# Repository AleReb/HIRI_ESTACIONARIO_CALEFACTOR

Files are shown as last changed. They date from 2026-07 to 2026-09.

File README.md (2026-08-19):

# HIRI AUCA con calefactor para Plantower

Proyecto de firmware y hardware para una estación ambiental HIRI AUCA basada en
ESP32, un sensor Plantower y un calefactor controlado por ESP8266. El calefactor
mide temperatura y humedad, protege el elemento térmico mediante termocupla y
entrega sus datos a la estación por un enlace serial dedicado.

## Estado vigente

| Componente | Archivo principal | Plataforma | Versión |
|---|---|---|---|
| Calefactor | `Calefactor_V2_0_0/Calefactor_V2_0_0.ino` | ESP8266 / NodeMCU | Firmware `1.0.0` |
| Estación HIRI | `HIRI_STATIC_CALEFACTOR_0_1/HIRI_STATIC_CALEFACTOR_0_1.ino` | ESP32 Dev Module | `CAL V0.0.1` |
| PCB calefactor | `PCB/calefactor.sch` y `PCB/calefactor.brd` | Autodesk EAGLE 9.6.2 | Diseño fuente |
| PCB HIRI ESP32/SIM7600 | `PCB/pcbesp32sim7600/Board_760032v2.sch` y `PCB/pcbesp32sim7600/Board_760032v2.brd` | Autodesk EAGLE 9.6.2 | Diseño fuente |
| PCB resistivo | `PCB/RESIS-CALOR.brd` | Autodesk EAGLE 9.6.2 | Diseño fuente |

El firmware histórico con DHT22 se conserva sólo como referencia. El calefactor
vigente usa SHT40; no requiere DHT22.

## Funciones principales

### Calefactor

- SHT40 para temperatura y humedad.
- BME280 como medición interna/respaldo.
- MAX6675 y termocupla para protección térmica.
- Relé en `D0`.
- Control por humedad con histéresis: enciende desde `65 % RH` y libera bajo
  `60 % RH`.
- Control por temperatura ambiental baja.
- Corte a `70 °C` y emergencia a `80 °C`.
- Prueba remota temporizada de 1 a 300 segundos, siempre subordinada a la
  protección térmica.
- Reinicio programado cada 4 horas.

### HIRI AUCA

- Plantower PMS por software serial.
- Enlace independiente a 9600 baudios con el calefactor.
- OLED SSD1306, RTC DS3231, tarjeta SD, batería y NeoPixel.
- SIM7600 para red celular, HTTP y GNSS configurable.
- Guardado SD cada 3 minutos y envío HTTP cada 5 minutos.
- Consulta opcional de versión del calefactor, sin bloquear calefactores
  antiguos.

## Protocolo serial HIRI-calefactor

Las tramas son ASCII a `9600 8N1` y terminan en `*HH`, donde `HH` es la suma
de comprobación hexadecimal de 8 bits del texto anterior al asterisco.

El identificador vigente del calefactor es `CALEF`; HIRI también acepta `CAL`
para equipos anteriores.

```text
HIRI,1,HELLO*HH
CALEF,1,HELLO,1.0.0*HH

HIRI,1,VERSION*HH
CALEF,1,VERSION,1.0.0*HH

HIRI,1,TEMP,valor*HH
HIRI,1,CAL,segundos*HH

CALEF,1,DATA,tempExt,tempSHT,tempBME,humSHT,humBME,tempTermocupla,
             rele,porHumedad,porTemperatura,emergencia*HH
```

La consulta `VERSION` es opcional. HIRI la envía al arrancar y luego cada 30
segundos durante un máximo de 3 minutos. La ausencia de respuesta no detiene el
arranque, la adquisición, el guardado ni el uso del calefactor.

## Estructura

- `Calefactor_V2_0_0/`: firmware vigente del calefactor.
- `HIRI_STATIC_CALEFACTOR_0_1/`: firmware vigente de la estación.
- `PCB/`: esquemáticos y placas EAGLE del calefactor, del elemento resistivo y
  de la estación HIRI con ESP32/SIM7600; consultar su README antes de fabricar.
- `documentacion/`: documentación del calefactor, cambios y antecedentes.
- `codigo_original/`: respaldos históricos; no son el firmware recomendado.

## Compilación

```powershell
arduino-cli compile --fqbn esp8266:esp8266:nodemcuv2 Calefactor_V2_0_0
arduino-cli compile --fqbn esp32:esp32:esp32 HIRI_STATIC_CALEFACTOR_0_1
```

Se requieren las librerías Arduino indicadas por los `#include` de cada
sketch. Antes de cargar, sustituir el puerto de ejemplo por el puerto real.

## Documentación

- [Documentación del calefactor](documentacion/README.md)
- [Documentación de HIRI](HIRI_STATIC_CALEFACTOR_0_1/README.md)
- [PCB y advertencias de fabricación](PCB/README.md)
- [Licencia y atribución](LICENSE.md)
- [Descargo de responsabilidad](DISCLAIMER.md)

## Autor y licencia

Creación original: **Alejandro Rebolledo**

Contacto: **arebolledo@udd.cl**

Salvo los componentes de terceros identificados por separado, el firmware, la
documentación y los diseños PCB originales de este repositorio se ofrecen bajo
[Creative Commons Attribution-NonCommercial 4.0 International](LICENSE.md).
Se permite compartir y adaptar con atribución, únicamente para fines no
comerciales. El uso comercial requiere autorización separada del autor.

Este proyecto se entrega tal cual y no constituye un producto certificado.
Revise el [descargo de responsabilidad](DISCLAIMER.md) antes de construir,
energizar o desplegar el equipo.

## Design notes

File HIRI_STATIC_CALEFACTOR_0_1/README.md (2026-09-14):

# HIRI AUCA 4 con calefactor

Firmware para una estación ambiental estática basada en ESP32. Integra un
Plantower, un calefactor externo, OLED, RTC, SD, batería, SIM7600 y GNSS
configurable.

## Estado vigente

- Sketch: `HIRI_STATIC_CALEFACTOR_0_1.ino`
- Plataforma: `esp32:esp32:esp32`
- Versión mostrada por el firmware: `CAL V1.0.1`
- Dispositivo activo: `HIRI-AUCA-4`
- `DEVICE_ID_STR`: `4`
- SSID local: `HIRI-AUCA-4`
- APN: `flolive.net`
- API: `http://api-sensores.cmasccp.cl/insertarMedicion`

## Hardware y pines

| Función | Pines ESP32 |
|---|---|
| SIM7600 | TX 27, RX 26, PWRKEY 4, DTR 32, FLIGHT 25 |
| Plantower PMS | RX 18, TX 5 por `SoftwareSerial` |
| Calefactor | RX2 19, TX2 23 a 9600 baudios |
| SD HSPI | SCLK 14, MISO 2, MOSI 15, CS 13 |
| Batería | ADC 35 |
| Alimentación auxiliar | GPIO 33 |
| NeoPixel | GPIO 12 |
| BTN1 | GPIO 39, activo en LOW y con resistencia externa |
| BTN2 | Deshabilitado (`-1`) |
| Enable/alimentación I2C | GPIO 0 (`I2C_POWER_PIN`) |
| OLED/RTC | Bus I2C: SDA 21 y SCL 22, valores predeterminados del ESP32 usados por `Wire.begin()` |

### Comportamiento actual de GPIO0 e I2C

El firmware vigente configura GPIO0 como salida y lo coloca directamente en
`HIGH` al comienzo de `setup()`. Después espera aproximadamente 600 ms antes de
ejecutar `Wire.begin()`. El bus se configura con timeout de 50 ms y reloj de
50 kHz.

La secuencia implementada actualmente es:

```text
GPIO0 OUTPUT
GPIO0 HIGH
espera 300 ms
inicialización Serial/watchdog
espera 300 ms
Wire.begin()
```

Esta variante **no ejecuta** el power-cycle `LOW -> HIGH` presente en el
firmware estático anterior. Tampoco contiene la función de recuperación
`recoverI2CBus()` ni el comando serial `i2c reset`.

Los comentarios de `config.h` describen GPIO0 como control activo en HIGH:
`LOW` corta la alimentación y `HIGH` energiza el bus. Esa es la intención del
firmware; durante diagnóstico de hardware se debe confirmar la polaridad real
midiendo tanto GPIO0 como la alimentación conmutada de OLED/RTC.

## Funciones activas

- Plantower: PM1.0, PM2.5, PM10 y T/RH cuando el modelo los entrega.
- Calefactor: SHT40, BME280, termocupla, relé y banderas de control.
- RTC DS3231.
- SD con CSV diario y archivos de error/transmisiones fallidas.
- HTTP por SIM7600.
- GNSS opcional; apagado por defecto.
- OLED con vistas rotativas de Plantower, calefactor y sistema; agrega GPS
  cuando GNSS está habilitado.
- Reinicio programado cada 3 horas.

## Detección y versión del calefactor

HIRI acepta el identificador vigente `CALEF` y el histórico `CAL`. Al arrancar
envía una consulta `VERSION` no bloqueante. Si no hay respuesta, reintenta cada
30 segundos durante un máximo de 3 minutos y luego deja de consultar.

La falta de versión no impide usar un calefactor antiguo. HIRI acepta tanto
`CAL,1,HELLO` sin versión como `CAL/CALEF,1,HELLO,<versión>`; `HELLO` o `DATA`
siguen estableciendo la conexión. Cuando se recibe una versión válida, se
muestra como `CALEFACTOR FW <versión>` en la OLED.

## Revisión de arranque

La ventana de inicio contiene:

```text
OLED
SD
RTC
PLANTOWER
CALEFACTOR
```

En `CALEFACTOR`, el estado inicial confirma que la UART quedó configurada. Si
la versión llega durante la ventana de revisión, se muestra en esa fila. La
ausencia de `VERSION` no se informa como fallo.

## Configuración operativa

En cada arranque el firmware fuerza:

```text
SD auto-mount:      ON
Guardado SD:        180000 ms (3 min)
Envío HTTP:         300000 ms (5 min)
Autostart:          ON
Esperar GPS:        OFF
```

Defaults al restablecer configuración:

```text
Timeout HTTP:       15 s
OLED auto-off:      OFF
NeoPixel:           ON, brillo 50 %
GNSS:               OFF
Modo GNSS:          15
Reinicio:           3 h
```

## Payload HTTP

Se envían exactamente 16 valores:

| Posición | Valor |
|---:|---|
| 1 | Latitud |
| 2 | Longitud |
| 3 | CSQ |
| 4 | Velocidad GNSS |
| 5 | Satélites |
| 6 | Voltaje |
| 7 | Temperatura Plantower |
| 8 | Humedad Plantower |
| 9 | PM1.0 |
| 10 | PM2.5 |
| 11 | PM10 |
| 12 | Temperatura SHT40 del calefactor |
| 13 | Humedad SHT40 del calefactor |
| 14 | Estado del relé |
| 15 | Temperatura BME280 del calefactor |
| 16 | Humedad BME280 del calefactor |

Los datos no disponibles se representan con `-1`.

Para `DEVICE_ID_STR = "4"`:

```text
idsSensores=1165,1165,1165,1165,1165,1166,1167,1167,1167,1167,1167,1203,1203,1203,1203,1203
idsVariables=11,12,15,45,46,4,3,6,7,8,9,3,6,57,58,59
```

## Tarjeta SD

Archivo diario:

```text
/HIRI_AUCA_4_DD_MM_AAAA.csv
```

Columnas:

```text
timestamp,pm_1_0_ug_m3,pm_2_5_ug_m3,pm_10_ug_m3,
temp_plantower_c,hum_plantower_pct,
temp_interna_calefactor_bme_c,hum_interna_calefactor_bme_pct,
temp_externa_calefactor_sht40_c,hum_externa_calefactor_sht40_pct,
relay_calefactor,senal_csq,conexion_http,
latitud,longitud,velocidad_kmh,satelites,voltaje_v
```

Archivos auxiliares:

- `/errors_h4.csv`
- `/failed_h4.csv`

## Interfaz actual

La pantalla normal rota automáticamente entre vistas de estación. BTN1 ejecuta
una prueba manual compuesta por envío HTTP, guardado SD y solicitud de
calefacción por 10 segundos. BTN2 avanzaría la pantalla, pero está deshabilitado
en la configuración de pines actual.

Las estructuras de menú todavía existen en `ui.ino`, pero el flujo de render y
botones vigente retorna desde la vista de estación antes de navegar esos menús.
Consulte `documentacion/menu_structure.md`.

## Compilación

Desde la carpeta superior:

```powershell
arduino-cli compile --fqbn esp32:esp32:esp32 HIRI_STATIC_CALEFACTOR_0_1
```

## Documentación, licencia y seguridad

- [Manual técnico](documentacion/MANUAL_TECNICO.md)
- [Manual de usuario](documentacion/MANUAL_USUARIO.md)
- [Interfaz actual](documentacion/menu_structure.md)
- [Licencia del proyecto](../LICENSE.md)
- [Descargo de responsabilidad](../DISCLAIMER.md)

Creación original: **Alejandro Rebolledo** (`arebolledo@udd.cl`).

Licencia: **CC BY-NC 4.0**.

## Proteccion de conexion y modo SD

`StrikesConect` es el contador global de intentos consecutivos de conexion;
`MAX_STRIKES_CONECT = 3` fija el limite. Se incrementa antes de entrar en las
llamadas bloqueantes y se limpia al establecer la conexion de datos. Se conserva
en memoria RTC ante reinicios por software/watchdog, sin escribir la flash.

Los fallos 1 y 2 provocan un reinicio controlado. El fallo 3 activa
`connectionOffline`: se suspenden los intentos celulares y GNSS, se mantiene
el muestreo y se intenta guardar en SD en la primera vuelta del loop y luego
cada 3 minutos. Si un reinicio interrumpe el tercer intento, el siguiente
arranque entra directamente en modo SD. Apagar y volver a encender inicia
una nueva serie de intentos. No hay recuperacion automatica de red en modo SD.

La cabecera muestra `SD OK` si esta montada y no se ha detectado un error de
escritura, o `SD ERR` si falta la tarjeta o falla abrir/escribir el CSV.
Sin SD ni conexion se siguen leyendo sensores, pero no se pueden conservar
las mediciones. No se implementa montaje automatico de una tarjeta insertada
posteriormente; se puede montar desde la funcion WiFi SD existente.

TinyGSM alimenta ahora el watchdog desde `TINY_GSM_YIELD`, dentro de sus esperas
AT. Un reset antes de este cambio podia ocurrir al esperar 60 segundos por la
red con un watchdog de 60 segundos. Tambien se elimino el pulso repetido de
PWRKEY durante la espera de arranque. Los tiempos de espera siguen siendo
bloqueantes; el cambio evita el reset del watchdog, no los convierte en tareas
asincronicas.

Pruebas de banco pendientes:

- Sin cobertura y con SD: verificar strikes 1, 2 y 3, solo dos reinicios y
  crecimiento del CSV cada 3 minutos con `SIN_RED_MODO_SD`.
- Sin cobertura ni SD: verificar modo de medicion estable y `SD ERR`.
- Con red desde encendido: verificar contador en cero y envio HTTP normal.
- Retirar la SD durante muestreo: verificar `SD ERR` tras el siguiente guardado.
- Cortar y restablecer alimentacion: verificar nuevos intentos de conexion.
- Revisar el motivo de reinicio serial para distinguir watchdog de brownout.

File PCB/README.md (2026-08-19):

# Diseños PCB

Esta carpeta contiene fuentes de Autodesk EAGLE 9.6.2:

| Archivo | Contenido observado | Dimensión aproximada |
|---|---|---:|
| `calefactor.sch` | Esquemático del controlador del calefactor, 1 hoja y 11 componentes | No aplica |
| `calefactor.brd` | Placa del controlador con Wemos D1 Mini Pro, termocupla, dos conectores I2C, relé y serial | 48,30 × 78,09 mm |
| `RESIS-CALOR.brd` | Placa alargada del elemento resistivo/calefactor | 120,40 × 24,00 mm |
| `pcbesp32sim7600/Board_760032v2.sch` | Esquemático de la estación HIRI para ESP32 y SIM7600 | No aplica |
| `pcbesp32sim7600/Board_760032v2.brd` | Placa de la estación HIRI correspondiente al firmware `HIRI_STATIC_CALEFACTOR_0_1` | Fuente EAGLE |

## Correspondencia con el firmware

El firmware vigente usa:

- Wemos/ESP8266;
- MAX6675 y termocupla;
- BME280 y SHT40 por I2C;
- relé;
- enlace serial con HIRI.

El esquemático y la placa conservan un conector rotulado `DHT`. Es una herencia
del diseño anterior y no significa que el firmware vigente utilice DHT22. El
SHT40 vigente se conecta por I2C. Antes de fabricar se debe comprobar en EAGLE
la asignación real de cada conector, señal y pin contra
`Calefactor_V2_0_0/Calefactor_V2_0_0.ino`.

El diseño `pcbesp32sim7600/Board_760032v2` corresponde al firmware de la
estación ubicado en
`HIRI_STATIC_CALEFACTOR_0_1/HIRI_STATIC_CALEFACTOR_0_1.ino`. Incluye la placa y
el esquemático para la electrónica basada en ESP32 y SIM7600, además de las
conexiones de los periféricos de HIRI. Antes de fabricar, también se deben
comparar las señales y los pines del diseño contra ese sketch.

## Estado de fabricación

No se incluyen Gerbers, archivos de perforado, BOM aprobada ni resultados de
DRC/ERC. Estos archivos deben considerarse fuentes editables, no un paquete de
fabricación liberado.

Antes de fabricar:

1. Ejecutar ERC en `calefactor.sch`.
2. Confirmar que `calefactor.brd` corresponde al esquemático vigente.
3. Ejecutar DRC con las reglas del fabricante.
4. Revisar anchos de pista, corriente, separación y aislamiento del circuito
   térmico y del relé.
5. Verificar huellas, polaridades, conectores y dimensiones mecánicas.
6. Revisar `RESIS-CALOR.brd` mediante cálculo térmico y eléctrico independiente.
7. Generar y revisar Gerbers y perforaciones antes de enviar a producción.
8. Ejecutar ERC y DRC sobre `pcbesp32sim7600/Board_760032v2.sch` y
   `pcbesp32sim7600/Board_760032v2.brd`, y verificar su correspondencia con el
   firmware HIRI vigente.

Consulte [el descargo de responsabilidad](../DISCLAIMER.md). Los diseños
originales se distribuyen bajo [CC BY-NC 4.0](../LICENSE.md).

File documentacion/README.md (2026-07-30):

# Documentación vigente del calefactor

Fuente de verdad:
`../Calefactor_V2_0_0/Calefactor_V2_0_0.ino`.

## Identificación

- Generación del proyecto: Calefactor V2.
- Versión de firmware: `1.0.0`.
- Plataforma: ESP8266 / NodeMCU.
- ID de protocolo vigente: `CALEF`.
- ID histórico aceptado por HIRI: `CAL`.

## Hardware utilizado por el firmware

| Función | Componente o pin |
|---|---|
| Temperatura/humedad externa | SHT40 por I2C |
| Temperatura/humedad interna | BME280 en dirección `0x76` |
| Protección térmica | MAX6675: SO `D6`, SCK `D5`, CS `D8` |
| Salida del relé | `D0` |
| Serial hacia HIRI | RX `D3`, TX `D4`, 9600 8N1 |

El DHT22 sólo pertenece al firmware histórico.

## Control implementado

- Muestreo cada 1 segundo.
- Humedad: activa desde `65 % RH`, desactiva bajo `60 % RH`.
- Temperatura mínima de referencia: `15 °C`.
- Corte de relé por termocupla inválida, igual a cero o desde `70 °C`.
- Emergencia desde `80 °C`; recuperación bajo `70 °C`.
- Prueba manual serial de 1 a 300 segundos con las mismas protecciones.
- Reinicio automático cada 4 horas.

## Protocolo

Las tramas usan checksum aditivo hexadecimal `*HH`.

```text
HIRI,1,HELLO*HH
HIRI,1,VERSION*HH
HIRI,1,TEMP,valor*HH
HIRI,1,CAL,segundos*HH

CALEF,1,HELLO,1.0.0*HH
CALEF,1,VERSION,1.0.0*HH
CALEF,1,DATA,...*HH
```

La consulta de versión no es obligatoria para operar. HIRI puede usar
calefactores antiguos que sólo entreguen `HELLO` o `DATA`.

## Documentos

- [Cambios V2](cambios_v2_0_0.md)
- [Revisión histórica del código DHT22](revision_codigo.md)
- [Humedad y medición PM2.5](humedad_pm25_literatura.md)
- [Recomendaciones de diseño](recomendaciones.md)
- [PCB](../PCB/README.md)

Los documentos históricos se conservan como antecedentes y están marcados como
tales. Para comportamiento ejecutable prevalece siempre el sketch vigente.

## Seguridad y licencia

Creación original: Alejandro Rebolledo, arebolledo@udd.cl.

Licencia: [CC BY-NC 4.0](../LICENSE.md).

Lea el [descargo de responsabilidad](../DISCLAIMER.md) antes de energizar el
calefactor o fabricar los PCB.

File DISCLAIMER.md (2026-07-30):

# Descargo de responsabilidad

Este repositorio contiene firmware experimental, diseños electrónicos y
documentación técnica. No constituye un producto terminado, certificado ni
aprobado para seguridad funcional, metrología reglamentaria, uso médico,
protección de personas o control de procesos críticos.

El calefactor puede involucrar temperaturas elevadas, corriente eléctrica,
elementos resistivos y relés. Un error de diseño, montaje, firmware, conexión,
selección de componentes o disipación puede producir sobretemperatura,
incendio, choque eléctrico, daño a sensores, pérdida de datos o lesiones.

Antes de construir o utilizar el sistema, el usuario o integrador debe:

- revisar independientemente esquemáticos, PCB, pistas, aislaciones,
  conectores, polaridades, protecciones y capacidad de corriente;
- instalar fusibles, límites térmicos independientes y medios de desconexión
  adecuados al riesgo;
- verificar la termocupla, el relé y el estado seguro ante fallas;
- validar el equipo en un entorno controlado antes del despliegue;
- realizar calibración y validación metrológica de los sensores;
- cumplir las normas eléctricas, ambientales, de radiofrecuencia, seguridad y
  protección de datos aplicables en el lugar de uso.

Los archivos PCB se entregan como fuentes de diseño y no como archivos de
fabricación aprobados. Deben pasar revisión eléctrica, mecánica, DRC/ERC y de
seguridad antes de generar Gerbers o fabricar.

El software, la documentación y el hardware se proporcionan **tal cual**, sin
garantías expresas ni implícitas de exactitud, seguridad, comerciabilidad,
ausencia de defectos o aptitud para un propósito particular. En la máxima
medida permitida por la ley, Alejandro Rebolledo y los colaboradores no asumen
responsabilidad por daños directos, indirectos, incidentales o consecuentes,
pérdida de datos, lucro cesante, lesiones o daños materiales derivados del uso
o imposibilidad de uso del proyecto.

El usuario es responsable de evaluar si el proyecto es apropiado para su caso
de uso y asume los riesgos de construcción, modificación, operación y
despliegue.

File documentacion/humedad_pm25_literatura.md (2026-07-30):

# Humedad relativa y sensores PM2.5 tipo Plantower

## Contexto

Los sensores Plantower/PMS5003 estiman PM por dispersion de luz. No pesan directamente el material particulado: convierten senales opticas en conteos y concentraciones mediante algoritmos internos. Por eso sus lecturas dependen de propiedades opticas, tamano de particula, composicion y humedad.

## Que dice la literatura

### 1. Plantower admite operacion hasta alta humedad, pero advierte condiciones con niebla/agua

El manual del PMS5003 indica rango de humedad de trabajo de `0~99%`. Tambien advierte que, en condiciones como niebla de agua, bano/termas u outdoor, se debe agregar proteccion. Esto significa que el sensor puede operar en aire humedo, pero no implica que la medicion sea exacta en alta humedad o con condensacion/aerosol de agua.

Fuente: Plantower PMS5003 series data manual.

### 2. La humedad relativa puede producir sobreestimacion

Una revision/laboratorio sobre sensores de bajo costo indica que, en humedad relativa alta, el efecto higroscopico puede sobreestimar la salida del sensor. Tambien cita que para Plantower PMS5003 el efecto empieza a observarse sobre aproximadamente 65-70% RH.

Fuente: *Calibration of Low-cost Sensors for Measurement of Indoor Particulate Matter Concentrations via Laboratory/Field Evaluation*, AAQR.

### 3. El mecanismo fisico es el crecimiento higroscopico

Cuando la humedad relativa sube, algunas particulas absorben agua. Eso cambia su tamano y su indice de refraccion efectivo. Como el sensor optico mide luz dispersada, puede interpretar ese cambio como mas particulas o mas masa PM2.5, aunque parte del aumento sea agua.

Fuente: Patel et al. 2024, *Towards a hygroscopic growth calibration for low-cost PM2.5 sensors*, Atmospheric Measurement Techniques.

### 4. La composicion del aerosol importa

El efecto de humedad no es igual para todos los aerosoles. Particulas con sulfatos, nitratos u otras fracciones mas higroscopicas absorben mas agua. Por eso una regla fija universal de humedad puede mejorar, pero no garantiza exactitud absoluta.

Fuente: Patel et al. 2024; Frontiers 2021 field evaluation of Plantower PMS5003.

### 5. Se han propuesto correcciones por humedad

Patel et al. 2024 desarrollan una calibracion para PMS5003 que incorpora crecimiento higroscopico y parametros estacionales. En San Francisco, la calibracion con dependencia estacional de RH redujo el RMSE cerca de 40% frente a datos sin calibrar.

## Implicancia para este calefactor

Si el calefactor esta antes del Plantower, su justificacion tecnica probable es reducir la humedad relativa del aire que entra al sensor, o evitar condensacion. Calentar el aire sin agregar vapor de agua baja la humedad relativa, aunque no cambia la humedad absoluta.

Ejemplo conceptual:

- Aire frio y humedo entra al sistema.
- El calefactor aumenta la temperatura del flujo.
- Al subir la temperatura, la capacidad del aire para contener vapor aumenta.
- La humedad relativa baja.
- Baja el riesgo de condensacion y se reduce parte del sesgo optico asociado al crecimiento higroscopico.

El firmware vigente mide humedad con SHT40 y usa una histéresis de `65 % RH` para activar y `60 % RH` para desactivar el control por humedad. Aún es recomendable registrar una medición adicional después del calefactor para validar experimentalmente la reducción de RH antes del Plantower.

## Umbrales utiles para documentar o probar

Estos valores no son reglas universales, pero sirven como punto de partida experimental:

- RH < 60%: zona generalmente menos problematica.
- RH 65-70%: literatura reporta inicio de efecto higroscopico en PMS5003 en algunos casos.
- RH 74-80%: estudios de laboratorio reportan debilitamiento de desempeno dependiendo de composicion.
- RH > 85%: evaluaciones de campo muestran influencia clara y respuesta no lineal.
- RH cercana a 95% o condensacion: zona de alto riesgo para datos y hardware.

## Fuentes consultadas

- Plantower PMS5003 series data manual: https://www.aqmd.gov/docs/default-source/aq-spec/resources-page/plantower-pms5003-manual_v2-3.pdf
- Patel, M. Y. et al. 2024. *Towards a hygroscopic growth calibration for low-cost PM2.5 sensors*. Atmospheric Measurement Techniques. https://amt.copernicus.org/articles/17/1051/2024/
- *Calibration of Low-cost Sensors for Measurement of Indoor Particulate Matter Concentrations via Laboratory/Field Evaluation*. AAQR. https://aaqr.org/articles/aaqr-23-04-jk-0097.pdf
- *Field Calibration and Evaluation of an Internet-of-Things-Based Particulate Matter Sensor*. Frontiers in Environmental Science. https://www.frontiersin.org/journals/environmental-science/articles/10.3389/fenvs.2021.798485/full

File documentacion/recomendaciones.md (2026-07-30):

# Recomendaciones y contexto histórico

> Nota de vigencia: el DHT22 fue retirado. El firmware activo usa SHT40 en `Calefactor_V2_0_0/Calefactor_V2_0_0.ino`. Las referencias siguientes a `dhthum` y `dhttemp` son ejemplos del firmware original y se conservan como antecedente.

## Diagnostico

El firmware original controlaba temperatura mínima y protección por sobretemperatura, pero no cerraba el lazo con humedad. El firmware vigente ya incorpora ese control mediante SHT40.

## Recomendacion principal

Usar una condición de control basada en humedad relativa, idealmente medida cerca de la entrada del Plantower y después del calefactor. En `Calefactor V2`, firmware `1.0.0`, se implementó con SHT40 e histéresis `65% RH ON / 60% RH OFF`.

Ejemplo histórico de regla simple con DHT22 (no usar en el firmware vigente):

```cpp
const float humedadObjetivo = 60.0;
const float humedadAlta = 70.0;

bool humedadAltaDetectada = (dhthum > humedadAlta || humBMP > humedadAlta);
bool temperaturaBaja = (tempBMP < minimo || tempsens < minimo || dhttemp < minimo);
bool calefactorSeguro = (tempThermo > 0 && tempThermo < maxcontrol);

if ((temperaturaBaja || humedadAltaDetectada) && calefactorSeguro) {
  digitalWrite(relay, HIGH);
} else {
  digitalWrite(relay, LOW);
}
```

Esta regla no debe copiarse sin probar: hay que decidir que sensor de humedad representa mejor el flujo que entra al Plantower.

## Mejor opcion de control

Usar dos criterios:

1. Seguridad termica del calefactor:
   - Apagar si `tempThermo >= maxcontrol`.
   - Emergencia si `tempThermo >= maxemergencia`.
   - Apagar ante falla de termocupla.

2. Calidad de medicion PM2.5:
   - Encender calefactor si RH antes del Plantower supera 65-70%.
   - Apagar o modular cuando RH baje a 55-60%.
   - Usar histeresis para evitar prendido/apagado rapido.

Ejemplo de histéresis implementada en el firmware 1.0.0:

```cpp
const float rhOn = 65.0;
const float rhOff = 60.0;
bool heaterByHumidity = false;

if (rhEntradaPlantower >= rhOn) {
  heaterByHumidity = true;
}
if (rhEntradaPlantower <= rhOff) {
  heaterByHumidity = false;
}
```

## Medicion recomendada

Para validar el sistema, registrar como minimo:

- PM1.0, PM2.5, PM10 del Plantower.
- Temperatura y humedad antes del calefactor.
- Temperatura y humedad despues del calefactor o cerca de la entrada del Plantower.
- Temperatura de la termocupla del calefactor.
- Estado del rele.
- Fecha/hora.

Con esos datos se puede comprobar si el calefactor realmente baja la humedad relativa que ve el Plantower.

## Punto de rocio

Una mejora es calcular punto de rocio. Si la temperatura del flujo o de superficies internas se acerca al punto de rocio, aumenta el riesgo de condensacion.

El control puede buscar:

- Mantener la temperatura del aire que entra al Plantower varios grados sobre el punto de rocio.
- Evitar exceder la temperatura maxima recomendada del sensor.

## Cambios de codigo recomendados

- DHT22 reemplazado por SHT40 en `Calefactor V2`, firmware `1.0.0`.
- Validar `isnan()` en lecturas ambientales. Implementado en el firmware `1.0.0`.
- Separar estado de sensores fallidos de valores fisicos como `999`.
- Incluir estado del rele en la salida de datos. Implementado en el firmware `1.0.0`.
- Incluir banderas de error: BME ausente, SHT40 inválido y termocupla inválida.
- Evitar `while (emergencyMode)` bloqueante; usar un estado de emergencia no bloqueante. Implementado en el firmware `1.0.0`.
- Cambiar `restartInterval` a `const unsigned long`. Implementado en el firmware `1.0.0`.
- Corregir comentarios con caracteres mal codificados.

## Decision tecnica

Para un documento academico o informe, la frase correcta seria:

> El prototipo mide humedad relativa, pero la version actual del firmware no la utiliza para controlar el calefactor. El control se basa en umbrales de temperatura y proteccion por termocupla. Dado que la literatura identifica la humedad relativa como un factor relevante en sensores opticos PM2.5 tipo Plantower, se recomienda incorporar una regla de control por RH o punto de rocio y validar experimentalmente la reduccion de RH en la entrada del sensor.

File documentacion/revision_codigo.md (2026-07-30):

# Revisión técnica histórica: firmware original con DHT22

> Este documento describe exclusivamente el firmware original respaldado en `codigo_original/Calefactor_bmp_dht22_serialcheck_v3_original.ino`. El firmware vigente usa SHT40 y está en `Calefactor_V2_0_0/Calefactor_V2_0_0.ino`; no utiliza DHT22.

Archivo analizado: `Calefactor_bmp_dht22_serialcheck_v3.ino`

## Hardware asumido

- MCU: ESP8266, por el uso de pines `D0`...`D8` y `ESP.wdtFeed()`.
- Sensor ambiental BME280 por I2C, direccion `0x76`.
- Sensor DHT22 en `D7`.
- Termocupla con MAX6675 por SPI en `D5`, `D6`, `D8`.
- Rele del calefactor en `D0`.
- Comunicacion serial secundaria por `SoftwareSerial`:
  - `externo_RX = D3`
  - `externo_TX = D4`

## Variables principales

- `tempsens`: temperatura recibida desde el puerto serial secundario. Parte en `16`.
- `tempBMP`: temperatura del BME280.
- `humBMP`: humedad relativa del BME280.
- `dhttemp`: temperatura del DHT22.
- `dhthum`: humedad relativa del DHT22.
- `tempThermo`: temperatura del calefactor medida por MAX6675.
- `minimo = 15`: umbral inferior de temperatura.
- `maxcontrol = 70`: temperatura maxima normal del calefactor.
- `maxemergencia = 80`: umbral de emergencia.

## Flujo de operacion

1. Inicializa watchdog, serial principal, serial externo, SPI, rele, MAX6675, BME280 y DHT22.
2. Si falla BME280, marca `statusBME = false` y despues reporta `999` en temperatura/humedad BME.
3. Cada vez que llega una linea por `externo`, valida checksum y actualiza `tempsens`.
4. Cada 280 ms lee:
   - MAX6675.
   - BME280, si esta disponible.
   - DHT22.
5. Imprime una linea CSV:

```text
tempsens,dhttemp,tempBMP,dhthum,humBMP,tempThermo
```

6. Enciende el rele si alguna de estas temperaturas esta bajo `15 C`:
   - `tempBMP`
   - `tempsens`
   - `dhttemp`
7. Apaga el rele si `tempThermo >= 70 C` o si `tempThermo == 0`.
8. Entra a modo emergencia si `tempThermo >= 80 C`; sale cuando baja de `80 C`.
9. Reinicia el ESP cada 4 horas con `Ticker`.

## Punto critico: humedad medida pero no usada

El codigo mide humedad:

```cpp
humBMP = bme.readHumidity();
dht.humidity().getEvent(&event);
dhthum = event.relative_humidity;
```

Pero la humedad solo se imprime/transmite. No aparece en la condicion de control del rele:

```cpp
if (tempBMP < minimo or tempsens < minimo or dhttemp < minimo)
```

Por lo tanto, si la humedad relativa sube a 70%, 80% o 90%, el calefactor no necesariamente encendera. Solo encendera si alguna temperatura baja de 15 C.

## Riesgos y observaciones

### 1. El calefactor no controla directamente la causa del sesgo PM2.5

La literatura indica que el problema de los sensores opticos PM2.5 no es solo baja temperatura, sino humedad relativa alta, condensacion y crecimiento higroscopico. El codigo actual no usa `dhthum` ni `humBMP` para activar el calefactor.

### 2. Lecturas invalidas del DHT22 no se filtran

Si el DHT22 entrega `NaN`, la comparacion `dhttemp < minimo` no se comporta como una lectura valida. Conviene validar con `isnan()`.

### 3. Uso de `tempBMP = 999` si falla BME280

Esto evita que el BME280 active el calefactor, pero tambien oculta la falla dentro de la logica de control. Para seguridad, una falla de sensor deberia quedar separada como estado de error.

### 4. `tempThermo == 0` apaga el rele

Puede ser una proteccion contra error de termocupla. Es correcto como idea, pero deberia documentarse y reportarse como falla. Una termocupla desconectada podria no entregar exactamente cero en todos los casos.

### 5. Modo emergencia con `while`

Durante emergencia el codigo queda bloqueado en un `while`. Sigue leyendo la termocupla y enviando datos, pero no procesa nuevas entradas seriales ni actualiza DHT/BME. Para seguridad esta bien apagar el rele, pero para telemetria conviene evitar bloqueo total.

### 6. Intervalo de lectura DHT22 demasiado corto

El loop intenta leer DHT22 cada 280 ms. El DHT22 normalmente requiere intervalos mas largos entre lecturas, tipicamente alrededor de 2 s. Leerlo tan rapido puede aumentar lecturas invalidas o repetidas.

### 7. `restartInterval` como `int`

`4 * 60 * 60 * 1000` cabe en un entero de 32 bits, pero no en 16 bits. En ESP8266 suele funcionar porque `int` es 32 bits, pero es mejor declararlo como `const unsigned long`.

### 8. `String` en ESP8266

El uso repetido de `String` en loops largos puede fragmentar memoria en algunos escenarios. Si el sistema debe operar meses, conviene evaluar buffers `char[]` o reducir concatenaciones.

## Interpretacion funcional

El programa actual puede describirse como:

> Controlador de calefactor por umbral de temperatura minima, con proteccion por termocupla y telemetria ambiental de temperatura/humedad.

No deberia describirse como:

> Controlador de humedad para estabilizar lecturas PM2.5.

Para que esa segunda frase sea correcta, la humedad debe entrar en la regla de control o al menos en un algoritmo de compensacion/documentacion experimental.

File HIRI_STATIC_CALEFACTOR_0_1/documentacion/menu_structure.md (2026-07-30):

# Interfaz OLED vigente

Este documento describe el flujo que realmente ejecuta `ui.ino`.

## Vista normal

`renderDisplay()` llama directamente a `drawStationView()`. La vista rota cada
10 segundos.

Con GNSS apagado:

1. Plantower.
2. Calefactor.
3. Estado de la estación.

Con GNSS encendido:

1. GPS y hora.
2. Plantower.
3. Calefactor.
4. Estado de la estación.

## Botones activos

### BTN1

En la vista normal realiza una prueba manual:

- envío HTTP;
- guardado SD del payload;
- solicitud de calefacción por 10 segundos.

También atiende cancelación o salida en algunos estados transitorios.

### BTN2

En la vista normal avanza a la siguiente pantalla. La configuración vigente usa
`BUTTON_PIN_2=-1`, por lo que no hay un segundo botón físico activo.

## Estados transitorios

El enum `DisplayState` conserva:

```text
DISP_NORMAL
DISP_SD_SAVED
DISP_MESSAGE
DISP_PROMPT
DISP_NETWORK
DISP_RTC
DISP_STORAGE
DISP_GPS
DISP_WIFI
```

Las rutinas de render para esos estados permanecen disponibles, aunque varias
se alcanzan sólo desde código o funciones heredadas.

## Menús retenidos pero no activos

`ui.ino` todavía declara arreglos para:

- menú principal;
- Mensajes;
- Configuración;
- Información.

Sin embargo, el render normal no dibuja esos menús y los manejadores BTN1/BTN2
retornan desde la lógica de vista de estación antes de ejecutar la navegación
heredada. Por tanto, esos arreglos no representan una interfaz accesible en el
firmware actual.

Si se reactiva el menú, se deben revisar los retornos anticipados de
`ui_btn1_click()`, `ui_btn2_click()` y `renderDisplay()`, asignar un GPIO real a
BTN2 y actualizar este documento y el manual de usuario.

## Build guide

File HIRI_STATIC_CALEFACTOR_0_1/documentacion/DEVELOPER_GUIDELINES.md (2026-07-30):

# Guía de mantenimiento

## Fuente de verdad

- Sketch principal: `HIRI_STATIC_CALEFACTOR_0_1.ino`
- Versión actual: variable `VERSION`, hoy `CAL V0.0.1`
- ID de estación: `DEVICE_ID_STR`, hoy `4`
- Protocolo de calefactor: `heater_serial.ino`

El directorio `build/` contiene artefactos y copias generadas; no debe usarse
como fuente para editar ni documentar.

## Regla de cambios

Todo cambio funcional debe:

1. actualizar `VERSION` según la política de releases;
2. registrarse en `documentacion/CAMBIOS.md`;
3. actualizar README y manuales afectados;
4. compilar con Arduino CLI;
5. validarse en hardware antes de declararse liberado.

## Elementos que deben mantenerse sincronizados

| Cambio | Documentos |
|---|---|
| Pines o hardware | README, manual técnico y PCB README |
| OLED o botones | manual de usuario y `menu_structure.md` |
| Protocolo del calefactor | ambos README y manual técnico |
| CSV o HTTP | README y manual técnico |
| Comandos | manuales técnico y de usuario |
| Defaults | README y manual técnico |
| Licencia/autoría | README, `LICENSE.md` y `DISCLAIMER.md` |

## Compilación

Desde la carpeta superior:

```powershell
arduino-cli compile --fqbn esp32:esp32:esp32 HIRI_STATIC_CALEFACTOR_0_1
```

Calefactor:

```powershell
arduino-cli compile --fqbn esp8266:esp8266:nodemcuv2 Calefactor_V2_0_0
```

## Checklist mínimo

- Compilan ambos sketches.
- HIRI acepta IDs `CALEF` y `CAL`.
- La falta de respuesta `VERSION` no bloquea la operación.
- Plantower y calefactor entregan datos o fallan de forma controlada.
- El CSV coincide con la cabecera documentada.
- HTTP contiene exactamente 16 valores.
- OLED y botones coinciden con `menu_structure.md`.
- SD, RTC, SIM7600, watchdog y reinicio programado funcionan.
- PCB se revisa mediante ERC/DRC antes de fabricación.

## Autoría y redistribución

Conservar la atribución a Alejandro Rebolledo (`arebolledo@udd.cl`), el aviso
CC BY-NC 4.0, la indicación de cambios y el descargo de responsabilidad.

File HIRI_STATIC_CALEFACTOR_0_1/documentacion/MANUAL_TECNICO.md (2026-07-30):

# Manual técnico — HIRI AUCA con calefactor

Referencia comprobada contra el código vigente el 30 de julio de 2026.

- Sketch principal: `HIRI_STATIC_CALEFACTOR_0_1.ino`
- Versión: `CAL V0.0.1`
- Equipo: `HIRI-AUCA-4`
- Plataforma: ESP32 Dev Module

## 1. Arquitectura

| Archivo | Responsabilidad vigente |
|---|---|
| `HIRI_STATIC_CALEFACTOR_0_1.ino` | Estados globales, `setup`, `loop`, arranque, telemetría y scheduler |
| `heater_serial.ino` | Protocolo serial con el calefactor |
| `PMSandSensorEXTRA.ino` | Lectura Plantower y LED de PM2.5 |
| `sd_card.ino` | CSV, errores y transmisiones fallidas |
| `http.ino` | Sesión HTTP mediante SIM7600 |
| `gps.ino` | GNSS, NMEA, diagnóstico y XTRA |
| `rtc.ino` | RTC y sincronización |
| `wifi.ino` | AP, DNS cautivo y gestor SD |
| `ui.ino` | OLED y botones |
| `config.h`, `config.ino` | Pines, preferencias y defaults |
| `serial_commands.ino` | Consola serial USB |
| `helpers.ino` | Valores seguros, reset y logging |
| `animacion.ino` | Animación inicial |

## 2. Pines

```text
SIM7600:    TX27 RX26 PWRKEY4 DTR32 FLIGHT25
Plantower:  RX18 TX5
Calefactor: RX19 TX23 (Serial2, 9600 8N1)
SD HSPI:    SCLK14 MISO2 MOSI15 CS13
Batería:    ADC35
Power:      GPIO33
NeoPixel:   GPIO12
BTN1:       GPIO39, activo LOW, requiere resistencia externa
BTN2:       -1, deshabilitado
```

OLED SSD1306 y RTC DS3231 comparten I2C. En esta variante no existe en el código
un `I2C_POWER_PIN` ni rutinas de inicialización para SHT/ENS/gas locales; esas
referencias pertenecían a variantes anteriores.

## 3. Secuencia de arranque

1. Inicia Serial USB y watchdog.
2. Configura I2C a 50 kHz.
3. Carga preferencias y fuerza la política operativa de estación.
4. Monta SD y crea el CSV diario.
5. Detecta OLED y ejecuta la animación.
6. Inicia Plantower y `Serial2`.
7. Envía una solicitud opcional de versión al calefactor.
8. Detecta RTC.
9. Muestra por 3 segundos la revisión OLED mientras continúa leyendo el enlace
   del calefactor.
10. Inicializa botones, SIM7600, red, XTRA y GNSS.
11. Activa autostart, logging SD y envío HTTP.

La ventana de arranque muestra `OLED`, `SD`, `RTC`, `PLANTOWER` y `CALEFACTOR`.
El estado del calefactor confirma la UART; no exige soporte de `VERSION`.

## 4. Protocolo del calefactor

Tramas ASCII con checksum aditivo de 8 bits:

```text
HIRI,1,HELLO*HH
HIRI,1,VERSION*HH
HIRI,1,TEMP,<valor>*HH
HIRI,1,CAL,<1-300>*HH

CALEF,1,HELLO,<version>*HH
CALEF,1,VERSION,<version>*HH
CALEF,1,DATA,<10 valores>*HH
```

HIRI acepta tanto `CALEF` como el ID histórico `CAL`. También acepta el
`HELLO` histórico sin campo de versión (`CAL,1,HELLO`).

`DATA` contiene, en orden: temperatura externa recibida, temperatura SHT40,
temperatura BME280, humedad SHT40, humedad BME280, termocupla, relé, activación
por humedad, activación por temperatura y emergencia.

La conexión se considera sin datos si pasan más de 5 segundos desde el último
`DATA`. HIRI envía temperatura al calefactor cada 2 segundos y `HELLO` cada 5
segundos.

`VERSION` es opcional y no bloqueante. Se consulta al inicio y cada 30 segundos
por hasta 3 minutos. Una respuesta recibida por `HELLO` o `VERSION` detiene los
reintentos.

## 5. Bucle principal

El `loop()`:

1. alimenta watchdog y procesa botones;
2. atiende WiFi/DNS/Web si ese modo está activo;
3. procesa GNSS;
4. actualiza sensores auxiliares y señal;
5. lee Plantower;
6. atiende el serial del calefactor;
7. procesa comandos AT;
8. muestrea batería;
9. actualiza OLED;
10. guarda SD según periodo;
11. transmite HTTP según periodo;
12. procesa comandos USB y reinicio programado.

## 6. Configuración persistente

Preferencias `config`:

```text
sdAuto, sdSavePer, httpPer, httpTO, oledOff, oledTO,
ledEn, ledBr, autoStart, autoGPS, autoGPSTO,
rotDisp, rebootH, gnssEn, gnssMode
```

En cada boot se fuerzan `sdAutoMount=true`, guardado a 180 s, HTTP a 300 s,
autostart activo y espera GPS desactivada. El reinicio programado por defecto es
cada 3 horas.

## 7. HTTP

Endpoint:

```text
http://api-sensores.cmasccp.cl/insertarMedicion
```

El payload contiene 16 valores:

```text
lat,lon,csq,velocidad,satelites,voltaje,
tempPMS,humPMS,pm1,pm25,pm10,
tempSHTcalefactor,humSHTcalefactor,rele,
tempBMEcalefactor,humBMEcalefactor
```

Los datos inválidos se convierten a `-1`. Para el ID 4 se usan los sensores
`1165`, `1166`, `1167` y `1203` según el mapeo de `getIdsSensores()`.

## 8. SD

Archivo diario:

```text
/HIRI_AUCA_4_DD_MM_AAAA.csv
```

Las 18 columnas registran fecha/hora, PM, T/RH Plantower, T/RH BME del
calefactor, T/RH SHT40 del calefactor, relé, CSQ, resultado HTTP, posición,
velocidad, satélites y voltaje.

Logs:

- `/errors_h4.csv`
- `/failed_h4.csv`

## 9. UI real

`renderDisplay()` muestra directamente `drawStationView()` y rota entre:

- Plantower;
- calefactor;
- sistema;
- GPS/hora, sólo cuando GNSS está habilitado.

BTN1 ejecuta envío HTTP manual, guardado del mismo payload y una prueba del
calefactor por 10 segundos. BTN2 avanzaría la vista, pero está deshabilitado por
`BUTTON_PIN_2=-1`.

Los arreglos de menú permanecen en el fuente, pero el flujo vigente de botones
y render retorna antes de utilizarlos. No se deben documentar como interfaz
operativa hasta reactivar esa navegación.

## 10. Comandos seriales relevantes

Baudrate USB: 115200.

```text
help, cal <1-300>
rtc, rtcsync, modemtime
counters, resetcnt, stats
sdinfo, sdlist, sdnew, sdclear
netinfo, csq, sysinfo, mem, reboot
start, stop, config, configsave, configreset
set sdauto ..., set sdsave ..., set httpsend ..., set httptimeout ...
set oledoff ..., set oledtime ..., set led ..., set ledbright ...
set autostart ..., set gnss ..., set autowaitgps ...
set autogpsto ..., set rotatedisplay ..., set reboot ..., set gnssmode ...
```

La lista exacta y validaciones están en `serial_commands.ino`; `help` imprime la
ayuda disponible en el firmware cargado.

## 11. Compilación y QA

```powershell
arduino-cli compile --fqbn esp32:esp32:esp32 HIRI_STATIC_CALEFACTOR_0_1
```

Validar en hardware: boot, OLED, RTC, SD, Plantower, calefactor nuevo y antiguo,
termocupla, relé, SIM7600, HTTP, CSV y reinicio programado.

## 12. Seguridad, autoría y licencia

Creación original: Alejandro Rebolledo (`arebolledo@udd.cl`).

Licencia: [CC BY-NC 4.0](../../LICENSE.md).

Descargo: [DISCLAIMER.md](../../DISCLAIMER.md).

La protección de software a 70/80 °C no reemplaza fusibles, límites térmicos
independientes, revisión eléctrica ni validación del integrador.

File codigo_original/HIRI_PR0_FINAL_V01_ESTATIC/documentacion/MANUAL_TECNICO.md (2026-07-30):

# FirmwarePro - Manual Técnico

Versión de referencia: **Pro V0.1.27R**  
Sketch principal: **`HIRI_PR0_FINAL_V01_ESTATIC.ino`**  
Objetivo: documentación técnica para operación, mantenimiento e integración de la estación HIRI PR0 estática.

---

## 1. Arquitectura general

Firmware modular en archivos `.ino`:

- `HIRI_PR0_FINAL_V01_ESTATIC.ino`: núcleo, `setup()`, `loop()`, estados globales, sensores base, módem y scheduler.
- `config.h` / `config.ino`: pines, estructura `SystemConfig`, persistencia y defaults.
- `gps.ino`: GNSS, parser NMEA, watchdog, diagnósticos y XTRA.
- `PMSandSensorEXTRA.ino`: PMS5003, SDS198 y LED PM2.5.
- `sd_card.ino`: CSV diario, errores, failed_tx, headers y rotación por día.
- `http.ino`: ciclo HTTP por comandos AT del SIM7600.
- `wifi.ino`: AP, WebServer, DNSServer y captive portal.
- `ui.ino`: menú OLED, pantallas de estado, botones y modo debug.
- `serial_commands.ino`: CLI serial completa.
- `rtc.ino`: RTC y sincronización de hora.
- `helpers.ino`: utilidades de valores seguros y logging.
- `animacion.ino`: animación de arranque.

---

## 2. Hardware y pines activos

Definidos en `config.h` para la variante HIRIDUST/VALPO:

```text
SIM7600: TX27, RX26, PWRKEY4, DTR32, FLIGHT25
PMS5003: RX18, TX5 (SoftwareSerial)
SDS198 / Serial2: RX23, TX19
Batería: ADC35
NeoPixel: GPIO12
SD HSPI: SCLK14, MISO2, MOSI15, CS13
BTN1: GPIO39
BTN2: deshabilitado por defecto (-1)
I2C enable/power: GPIO0
```

Notas:

- `BTN1` usa lectura activa en LOW y requiere resistencia externa según la placa usada.
- `BTN2` solo se habilita si `BUTTON_PIN_2` se cambia desde `-1` a un GPIO real.
- `I2C_POWER_PIN` usa GPIO0 para controlar alimentación/enable de OLED y sensores I2C. En `setup()` parte en LOW, luego sube a HIGH, espera estabilización y recién después inicializa `Wire`.
- `POWER_PIN` existe como referencia histórica, pero no está activo en el flujo actual.

### Secuencia de alimentación I2C y OLED

1. `pinMode(I2C_POWER_PIN, OUTPUT)`.
2. `I2C_POWER_PIN = LOW` durante una ventana breve.
3. `I2C_POWER_PIN = HIGH`.
4. Espera de estabilización.
5. `configureI2CBus()` con `Wire.setTimeOut(50)` y reloj I2C a 50 kHz.
6. Detección de OLED en `0x3C` o `0x3D`.
7. `u8g2.begin()` y animación de arranque.
8. Ventana única de revisión de inicio.

La recuperación `recoverI2CBus()` ejecuta el mismo power-cycle sobre GPIO0, reinicia `Wire`, redetecta OLED y vuelve a inicializar sensores.

---

## 3. Configuración persistente

Namespace `config`:

- `sdAuto`, `sdSavePer`
- `httpPer`, `httpTO`
- `oledOff`, `oledTO`
- `ledEn`, `ledBr`
- `autoStart`, `autoGPS`, `autoGPSTO`, `autoDbg`
- `rotDisp`
- `gnssEn`, `gnssMode`

Defaults vigentes:

```text
sdAutoMount = true
sdSavePeriod = 180000 ms
httpSendPeriod = 300000 ms
httpTimeout = 15 s
oledAutoOff = false
ledEnabled = true
ledBrightness = 50 %
autostart = true
autostartWaitGps = false
autoDebug = true
rotateDisplay = false en configSetDefaults()
gnssEnabled = false
gnssMode = 15
```

Namespace `system`:

- `sendCnt`
- `sdCnt`
- `csvFile`
- `streaming`

Namespace `rtc`:

- `syncCnt`

---

## 4. Máquina de estados operativa

Estados funcionales relevantes:

- `streaming`: habilita transmisión HTTP periódica.
- `loggingEnabled`: habilita guardado SD periódico.
- `wifiModeActive`: habilita modo AP/Web.
- `uiFullMode`: activa vista completa/modo debug.
- `displayState`: subestados de UI (`DISP_NORMAL`, `DISP_MESSAGE`, `DISP_PROMPT`, `DISP_NETWORK`, `DISP_RTC`, `DISP_STORAGE`, `DISP_GPS`, `DISP_WIFI`).

Bucle principal:

1. Alimenta watchdog.
2. Procesa botones.
3. Si `wifiModeActive`, atiende DNS/WebServer, refresca display y retorna.
4. Si no hay WiFi activo:
   - Ejecuta GNSS solo si `config.gnssEnabled`.
   - Actualiza sensores.
   - Lee PMS/SDS198.
   - Actualiza LED PM2.5.
   - Atiende AT async.
   - Muestrea batería.
   - Refresca OLED.
   - Ejecuta watchdog de red, backoff HTTP y health log.
   - Guarda SD según `sdSavePeriod`.
   - Envía HTTP según `httpSendPeriod`.
   - Atiende comandos seriales.

---

## 5. Sensores

Sensores actuales:

- PMS5003: PM1.0, PM2.5, PM10, temperatura y humedad si están disponibles.
- SDS198: PM100/TSP por `Serial2`.
- SHT4x: temperatura y humedad externa principal.
- SHT31: temperatura y humedad alternativa/compatibilidad.
- DFRobot MultiGas I2C: concentración de gas.
- ENS160: TVOC, eCO2, AQI y validación de estado.
- RTC DS3231: tiempo y temperatura interna.
- ADC batería: promedio suavizado.

Mecanismos de robustez:

- Revisión secuencial de arranque por sensor con estado en Serial y OLED.
- Recuperación de bus I2C ante fallas repetidas.
- Power-cycle de OLED/sensores I2C usando GPIO0.
- Reintento/reinicialización para SHT4x y ENS160.
- Valores seguros para HTTP cuando una lectura no está disponible.

Durante el arranque se muestra una sola ventana de revisión con filas:

```text
I2C, OLED, SD, RTC, SHT4, SHT31, ENS, GAS
```

Cada fila se actualiza de `WAIT` a `...` y finalmente a `OK` o `FAIL`. Al terminar, la ventana queda visible cerca de 3 segundos.

---

## 6. GNSS

El subsistema GNSS existe, pero en la configuración de estación está **desactivado por defecto** (`gnssEnabled = false`).

Funciones clave:

- `gnssBringUp()`
- `setGnssAllWithFallback()`
- `gnssWatchdog()`
- `parseNMEA()`, `parseGGA()`, `parseRMC()`, `parseVTG()`, `parseGSA()`, `parseGSV()`
- `gnssDiagTick()`
- `gnssDebugPollAsync()`
- `detectAndEnableXtra()`
- `downloadXtraOnce()`
- `downloadXtraIfDue()`

Modos GNSS soportados:

- `1`: GPS
- `3`: GPS + GLONASS
- `5`: GPS + BEIDOU
- `7`: GPS + GLONASS + BEIDOU
- `15`: todas las constelaciones soportadas

---

## 7. SD y trazabilidad

`sd_card.ino` implementa:

- `generateCSVFileName()`: archivo diario por ID.
- `writeCSVHeader()`: cabecera controlada.
- `saveCSVData()`: registro de muestra y nota one-shot.
- `saveFailedTransmission()`: registro forense de fallas HTTP.
- `writeErrorLogHeader()`: log estructurado de errores.

Formato del CSV principal:

```text
ts_ms,time,gpsDate,lat,lon,alt,spd_kmh,pm1,pm25,pm10,pmsTempC,pmsHum,rtcTempC,batV,csq,sats,hdop,xtra_ok,sht31TempC,sht31Hum,sht4xTempC,sht4xHum,resetReason,pm100,gasPpm,tvoc,eco2,aqi,notas
```

Archivos:

- `/hiripro<ID>_DD_MM_YYYY.csv`
- `/errors_h<ID>.csv`
- `/failed_h<ID>.csv`

---

## 8. HTTP y red celular

Endpoint:

```text
http://api-sensores.cmasccp.cl/insertarMedicion
```

APN:

```text
flolive.net
```

Flujo HTTP:

1. Validación PDP/red.
2. `HTTPINIT`.
3. `HTTPPARA CID`.
4. `HTTPPARA URL`.
5. `HTTPACTION=0`.
6. Parseo de `+HTTPACTION:`.
7. `HTTPREAD` opcional.
8. `HTTPTERM`.

Mecanismos de robustez:

- Timeout configurable.
- Watchdog feed durante esperas.
- Registro de errores.
- Registro de URL fallida en SD.
- Contador de fallas consecutivas.
- Backoff HTTP tras fallas repetidas.
- Recuperación de módem.

---

## 9. Mapeo HTTP de sensores

`DEVICE_ID_STR` activo:

```text
12
```

`idsSensores` para dispositivo 12:

```text
1128,1129,1129,1130,1130,1130,1130,1130,1131,1132,1132,1132,1132,1132,1133,1134,1134
```

`idsVariables` común:

```text
53,54,55,11,12,15,45,46,4,3,6,7,8,9,51,3,6
```

Orden de `valores`:

```text
SO2/gas, TVOC, eCO2, latitud, longitud, CSQ, velocidad, satélites,
batería, temperatura PMS, humedad PMS, PM1.0, PM2.5, PM10,
PM100 SDS198, temperatura SHT, humedad SHT
```

Los datos faltantes o inválidos se envían como `-1`.

---

## 10. WiFi AP y gestor SD

`wifi.ino` implementa:

- `WiFi.softAP`.
- IP típica `192.168.4.1`.
- `DNSServer` en puerto 53.
- WebServer en puerto 80.

Rutas principales:

- `/`
- `/download`
- `/delete`
- `/rename`
- `/upload`
- `/delete_all`
- `/ip`
- `/ssid`

Controles:

- Sanitización básica de nombres.
- Validación de SD disponible.
- Límite de listado.
- Modo WiFi exclusivo para priorizar transferencias.

---

## 11. UI y botones

`ui.ino` implementa:

- Navegación por menú OLED.
- Confirmación para iniciar/detener muestreo.
- Pantallas de red, RTC, GPS y almacenamiento.
- Modo debug/full de telemetría.
- Pantalla WiFi dedicada.
- Notas one-shot desde menú Mensajes.

Controles lógicos:

- BTN1: navegar/cancelar; en modo debug ejecuta acción rápida de muestreo/transmisión.
- BTN2: seleccionar/confirmar; en modo debug sale al menú; en pantalla WiFi alterna WiFi SD.

En hardware actual, BTN2 está deshabilitado por defecto hasta asignar un GPIO real.

---

## 12. Serial CLI

Implementación en `serial_commands.ino`, entrada con `\n`, case-insensitive.

Comandos:

- `help`, `?`
- `rtc`, `rtcsync`, `modemtime`
- `counters`, `resetcnt`, `stats`
- `sdinfo`, `sdlist`, `sdnew`, `sdclear`, `sdclear confirm`
- `netinfo`, `csq`
- `sysinfo`, `mem`, `reboot`
- `i2c reset`
- `start`, `stop`
- `config`, `config sd`, `config http`, `config display`, `config power`
- `set sdauto on|off`
- `set sdsave 3|60|600|1200`
- `set httpsend 3|60|600|1200`
- `set httptimeout 5-30`
- `set oledoff on|off`
- `set oledtime 60|120|180`
- `set led on|off`
- `set ledbright 10|25|50|100`
- `set autostart on|off`
- `set gnss on|off`
- `set autowaitgps on|off`
- `set autogpsto 60-900`
- `set autodebug on|off`
- `set rotatedisplay on|off`
- `set gnssmode 1|3|5|7|15`
- `configreset`
- `configsave`

---

## 13. Validación QA

### Build

```bash
arduino-cli compile --fqbn esp32:esp32:esp32 .
```

### Flash

```bash
arduino-cli upload -p COMx --fqbn esp32:esp32:esp32 .
```

### Smoke test

1. Boot sin loop de reset.
2. GPIO0 sube a HIGH antes de inicializar I2C.
3. OLED muestra animación con versión e ID.
4. Ventana de revisión muestra `I2C`, `OLED`, `SD`, `RTC`, `SHT4`, `SHT31`, `ENS` y `GAS` con `OK/FAIL`.
5. SD monta y crea CSV.
6. Sensores entregan valores o fallan con logs controlados.
5. Módem registra red y obtiene CSQ.
6. HTTP responde o deja trazabilidad en `failed_h<ID>.csv`.
7. WiFi AP aparece como `HIRIPRO_12`.
8. Web SD responde en `192.168.4.1`.

Si GNSS se habilita, agregar validación de fix, satélites, HDOP y NMEA.

---

## 14. Riesgos y mejoras sugeridas

- Password AP por defecto fija.
- Falta autenticación HTTP para gestión SD.
- GNSS apagado por defecto puede producir campos de ubicación inválidos si no se habilita explícitamente.
- BTN2 deshabilitado requiere validación de flujo de UI según hardware final.
- Conviene agregar endpoint `/health`.
- Conviene automatizar pruebas de comandos seriales.
- Validar calibración de sensores antes de despliegue formal.

---

## Apéndice A. Logs frecuentes

- `[BOOT]`, `[READY]`
- `[MODEM]`, `[NET]`
- `[GNSS]`, `[GNSSDIAG]`, `[GSA]`, `[GSV]`
- `[HTTP]`
- `[SD]`, `[FAILED_TX]`
- `[CONFIG]`, `[SYSTEM]`
- `[UI]`

---

## Apéndice B. Disclaimer

Este firmware y este documento técnico se entregan **"as-is"** (tal cual), sin garantía de funcionamiento ininterrumpido ni adecuación a un caso de uso específico.

La validación metrológica, seguridad eléctrica, cumplimiento regulatorio y operación final son responsabilidad del integrador/desplegador.

Los autores no asumen responsabilidad por daños, pérdidas de datos o consecuencias derivadas del uso del sistema.

---

## Apéndice C. Licencia de documentación

Este manual se distribuye bajo:

**Creative Commons Attribution-NonCommercial 4.0 International (CC BY-NC 4.0)**  
https://creativecommons.org/licenses/by-nc/4.0/

Permisos principales:

- Compartir y adaptar con atribución.
- Uso no comercial.

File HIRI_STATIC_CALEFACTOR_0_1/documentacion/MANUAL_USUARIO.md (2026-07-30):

# Manual de usuario — HIRI AUCA 4

Firmware: `CAL V0.0.1`

Equipo: `HIRI-AUCA-4`

## Encendido

1. Compruebe cableado, antenas, termocupla, relé, Plantower y tarjeta SD.
2. Energice la estación y el calefactor.
3. La OLED muestra la animación y luego revisa:
   `OLED`, `SD`, `RTC`, `PLANTOWER` y `CALEFACTOR`.
4. La fila del calefactor confirma que el puerto serial fue iniciado. Si el
   equipo soporta consulta de versión, aparecerá su número.
5. La falta de número de versión no es un error: los calefactores antiguos
   siguen operando mediante sus datos normales.
6. La estación inicia automáticamente guardado SD y telemetría.

## Pantallas

Sin GNSS, la OLED rota entre:

- Plantower: PM1.0, PM2.5, PM10 y T/RH;
- calefactor: versión cuando existe, SHT40, BME280, termocupla y relé;
- sistema: ID, versión HIRI, batería, señal, contadores y modo.

Con GNSS habilitado se agrega GPS y hora.

## Botones

- BTN1 (GPIO39): ejecuta una acción manual de prueba:
  1. intenta un envío HTTP;
  2. guarda el mismo payload en SD;
  3. solicita 10 segundos de calefacción.
- BTN2 está deshabilitado en el firmware actual (`BUTTON_PIN_2=-1`).

La prueba térmica sólo es una solicitud: el calefactor la rechaza o la corta si
la termocupla es inválida, llega a 70 °C o existe una emergencia.

## Operación automática

```text
Guardado SD: cada 3 minutos
Envío HTTP: cada 5 minutos
Reinicio programado: cada 3 horas
GNSS: apagado por defecto
```

La estación consulta opcionalmente el firmware del calefactor durante los
primeros 3 minutos. Esas consultas no interrumpen ninguna otra función.

## Archivos SD

Datos diarios:

```text
/HIRI_AUCA_4_DD_MM_AAAA.csv
```

Logs:

```text
/errors_h4.csv
/failed_h4.csv
```

El CSV contiene PM, temperaturas, humedades, estado del relé, señal, resultado
HTTP, GNSS y batería.

## Consola USB

Conectar a 115200 baudios y terminación de línea `\n`.

Comandos útiles:

```text
help
cal 10
sdinfo
sdlist
netinfo
csq
sysinfo
start
stop
config
```

Use `cal N` sólo durante una prueba supervisada; `N` debe estar entre 1 y 300
segundos.

## Solución de problemas

### El calefactor no muestra versión

Puede ser un firmware antiguo. Si llegan mediciones y la pantalla indica datos
del calefactor, puede usarse normalmente. HIRI deja de consultar la versión
después de 3 minutos.

### No llegan datos del calefactor

- Verifique cruce TX/RX: calefactor TX hacia ESP32 RX19 y calefactor RX desde
  ESP32 TX23.
- Confirme 9600 baudios y tierra común.
- Revise las tramas `[CALEFACTOR]` en el monitor serial.
- Compruebe alimentación del ESP8266.

### No guarda en SD

Ejecute `sdinfo`, revise la tarjeta y compruebe que exista el archivo diario.

### No transmite

Ejecute `csq` y `netinfo`; revise antena, SIM, cobertura y
`/failed_h4.csv`.

### Lectura térmica inválida

No fuerce el relé. Revise MAX6675, termocupla, polaridad y conexión antes de
continuar.

## Seguridad y licencia

No deje una prueba del calefactor sin supervisión. El software no sustituye
protecciones térmicas y eléctricas independientes.

Autor original: Alejandro Rebolledo (`arebolledo@udd.cl`).

Licencia: [CC BY-NC 4.0](../../LICENSE.md).

Lea el [descargo de responsabilidad](../../DISCLAIMER.md).

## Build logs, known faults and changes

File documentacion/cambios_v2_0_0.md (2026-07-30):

# Cambios implementados en Calefactor V2 — firmware 1.0.0

## Control de version del firmware

La generacion de hardware/proyecto sigue siendo `Calefactor V2`. Su primera
version completa de firmware se identifica semanticamente como `1.0.0` mediante
la constante `CAL_FIRMWARE_VERSION`.

HIRI puede consultarla por el enlace serial de 9600 baudios:

```text
HIRI,1,VERSION*HH
CALEF,1,VERSION,1.0.0*HH
```

`HH` es la suma de comprobacion hexadecimal ya usada por el protocolo. La trama
`HELLO` tambien incluye la version para conservar la deteccion existente.

Archivo nuevo:

```text
Calefactor_V2_0_0/Calefactor_V2_0_0.ino
```

Respaldo del codigo original:

```text
codigo_original/Calefactor_bmp_dht22_serialcheck_v3_original.ino
```

## Cambio de sensor

Se elimino el uso de DHT22:

```cpp
#include <DHT.h>
#include <DHT_U.h>
```

Se agrego SHT40 por I2C usando la libreria de Adafruit:

```cpp
#include <Adafruit_SHT4x.h>
Adafruit_SHT4x sht4 = Adafruit_SHT4x();
```

La lectura principal de humedad para el control es `shtHum`. Si el SHT40 falla, el codigo puede usar `humBME` como respaldo.

## Nueva regla de activacion por humedad

La literatura reporta que el efecto higroscopico en PMS5003 puede comenzar cerca de `65-70% RH`. Por eso la version V2 usa:

```cpp
const float RH_ON = 65.0;
const float RH_OFF = 60.0;
const float RH_ALTA = 70.0;
```

La logica queda:

- Si `RH >= 65%`, el calefactor queda habilitado por humedad.
- Si `RH <= 60%`, se deshabilita el control por humedad.
- Si `RH >= 70%`, se imprime un aviso porque ya esta en zona alta de posible sesgo higroscopico.

La histeresis evita que el rele prenda y apague continuamente cerca de un solo umbral.

## Proteccion termica

Se mantiene la termocupla MAX6675 como proteccion del calefactor:

- Apaga el rele si la termocupla es invalida o entrega `0`.
- Apaga el rele si `tempThermo >= 70 C`.
- Entra en emergencia si `tempThermo >= 80 C`.
- Sale de emergencia solo cuando `tempThermo < 70 C`.

## Control combinado

El rele se activa si hay condicion de humedad o condicion de temperatura baja:

```cpp
setRelay(heaterByHumidity || heaterByTemperature);
```

Pero esa activacion solo ocurre si la termocupla esta en rango seguro.

## Salida de datos del firmware 1.0.0

La nueva salida CSV es:

```text
tempsens,shtTemp,tempBME,shtHum,humBME,tempThermo,relayOn,heaterByHumidity,heaterByTemperature,emergencyMode
```

Donde:

- `tempsens`: temperatura recibida por serial externo.
- `shtTemp`: temperatura del SHT40.
- `tempBME`: temperatura del BME280.
- `shtHum`: humedad relativa del SHT40.
- `humBME`: humedad relativa del BME280.
- `tempThermo`: temperatura de la termocupla MAX6675.
- `relayOn`: `1` si el rele esta encendido, `0` si esta apagado.
- `heaterByHumidity`: `1` si la humedad esta pidiendo calefaccion.
- `heaterByTemperature`: `1` si alguna temperatura baja esta pidiendo calefaccion.
- `emergencyMode`: `1` si esta en modo emergencia.

## Librerias requeridas

Ademas de las librerias ya usadas por el proyecto, el firmware 1.0.0 requiere:

- `Adafruit SHT4x Library`
- `Adafruit BusIO`
- `Adafruit Unified Sensor`

## Recomendacion de prueba

Antes de conectar el Plantower a una campana o flujo real, probar con monitor serial:

1. Confirmar que `shtHum` y `shtTemp` entregan valores validos.
2. Subir RH sobre `65%` y verificar `heaterByHumidity = 1` y `relayOn = 1`.
3. Bajar RH bajo `60%` y verificar `heaterByHumidity = 0`.
4. Calentar termocupla sobre `70 C` y verificar que `relayOn = 0`.
5. Confirmar que el rele no enciende si la termocupla falla o marca `0`.

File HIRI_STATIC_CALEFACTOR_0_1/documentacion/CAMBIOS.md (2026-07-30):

# Registro de Cambios - FirmwarePro

## [CAL V0.0.1] - 2026-07-30
### Integracion del calefactor, documentacion y PCB

- Durante la revision de arranque se envia `HIRI,1,VERSION` sin esperar ni
  bloquear el resto de la inicializacion.
- La consulta de version es opcional: un calefactor antiguo que no implemente
  `VERSION` sigue siendo detectado y utilizado mediante `HELLO` y `DATA`.
- La version recibida aparece en la fila `CALEFACTOR` de la ventana de arranque
  y en la ventana operativa del calefactor.
- Mientras no se conozca la version, HIRI repite la consulta cada 30 segundos
  durante un maximo de 3 minutos. Las consultas son no bloqueantes y luego se
  detienen; esto no afecta el uso de calefactores antiguos.
- La version incluida en `HELLO` se conserva como respaldo de compatibilidad.
- HIRI acepta el identificador vigente `CALEF` y el historico `CAL`.
- Se sincronizan README, manual tecnico, manual de usuario y descripcion de UI
  con el codigo ejecutable actual.
- Se documentan los diseños EAGLE de `PCB/` y sus validaciones pendientes.
- Se incorpora atribucion a Alejandro Rebolledo, licencia CC BY-NC 4.0 y
  descargo de responsabilidad en la raiz del proyecto.

> Las entradas siguientes describen variantes historicas y se conservan como
> registro; no representan necesariamente el firmware vigente.

## [Pro V0.1.27R] - 2026-05-29
### Control de alimentacion I2C por GPIO0 y revision OLED de arranque

- Se documenta GPIO0 como `I2C_POWER_PIN` para enable/alimentacion de OLED y sensores I2C.
- Se documenta secuencia de arranque: GPIO0 LOW, GPIO0 HIGH, inicializacion de `Wire`, deteccion OLED y animacion HIRI.
- La animacion muestra version arriba a la derecha e ID del dispositivo abajo a la derecha.
- Se agrega ventana unica de revision de inicio con estados `WAIT`, `...`, `OK` y `FAIL` para:
  - I2C.
  - OLED.
  - SD.
  - RTC.
  - SHT4.
  - SHT31.
  - ENS.
  - GAS.
- La ventana de revision queda visible cerca de 3 segundos antes de continuar con modem/red.
- Se documenta comando serial `i2c reset` para cortar/reactivar GPIO0, reiniciar bus I2C, redetectar OLED y volver a revisar sensores.
- Se actualiza documentacion a `DEVICE_ID_STR = "12"`, AP `HIRIPRO_12` y mapeo HTTP del dispositivo 12.
- Se corrige el periodo operativo de guardado SD documentado a 180 s / 3 min.

Impacto:

- Cambio documental alineado con firmware actual.
- Reduce riesgo de confundir GPIO0 con boton; GPIO0 queda definido como enable/power-cycle I2C.

## [Pro V0.1.15V] - 2026-04-30
### Sincronización de documentación con firmware actual

- Se actualizó la documentación para reflejar el sketch activo `HIRI_PR0_FINAL_V01_ESTATIC.ino`.
- Se actualizó la versión documentada a **Pro V0.1.15V**.
- Se documentó `DEVICE_ID_STR = "10"` y el AP WiFi `HIRIPRO_10`.
- Se documentó la configuración activa HIRIDUST/VALPO:
  - BTN1 en GPIO39.
  - BTN2 deshabilitado por defecto (`BUTTON_PIN_2 = -1`).
  - PMS5003 en RX18/TX5.
  - SDS198 por `Serial2` en RX23/TX19.
  - SD por HSPI en SCLK14/MISO2/MOSI15/CS13.
- Se actualizó la lista de sensores documentados:
  - PMS5003.
  - SDS198.
  - SHT4x/SHT31.
  - DFRobot MultiGas I2C.
  - ENS160.
  - RTC DS3231.
- Se documentaron los defaults operativos actuales:
  - Guardado SD cada 30 segundos.
  - Envío HTTP cada 5 minutos.
  - Autostart activado.
  - Auto debug activado.
  - GNSS desactivado por defecto.
- Se actualizó el formato CSV con columnas de SHT4x, gas, TVOC, eCO2, AQI y `notas`.
- Se documentaron archivos auxiliares:
  - `/errors_h<ID>.csv`
  - `/failed_h<ID>.csv`
- Se corrigió el valor de datos HTTP faltantes o inválidos: actualmente se envían como `-1`.
- Se actualizó el mapeo HTTP para dispositivo 10.
- Se corrigieron comandos de compilación/carga Arduino CLI para usar la carpeta actual:
  - `arduino-cli compile --fqbn esp32:esp32:esp32 .`
  - `arduino-cli upload -p COMx --fqbn esp32:esp32:esp32 .`

Impacto:

- Cambio documental. No modifica firmware.
- Reduce riesgo de operar con instrucciones antiguas de pines, versión, CSV o comandos de build.

## [V0.1.0] - 2026-02-14
### Primera versión formal (baseline de producto)

- Se establece versión de firmware en código a **Pro V0.1.0**.
- Ajustes finales de UI WiFi:
  - Pantalla WiFi dedicada mostrando SSID, PASS e IP.
  - Control por botones según estado WiFi.
  - Con WiFi activo, pantalla bloqueada para evitar salida accidental.
  - Toggle ON/OFF por BTN2.
- Se repone feedback visual de arranque de módem:
  - Parpadeo de LED RGB durante `MODEM Starting...`.
- Documentación ordenada en carpeta `documentacion/` con `README.md` en raíz y `LICENSE` en root del repo.

## [V0.0.35] - 2026-02-14
### WiFi SD, documentación y control de release

- Se consolidó versión de firmware a **Pro V0.0.35**.
- Se implementó flujo de **WiFi SD** con mejoras para uso desde Windows mediante captive portal DNS.
- Se creó documentación formal en Markdown:
  - `README.md`
  - `MANUAL_USUARIO.md`
  - `MANUAL_TECNICO.md`
  - `LICENSE` (CC BY-NC 4.0)
- Se realizó recuperación/validación de estabilidad tras pruebas.
- Commit con funcionamiento confirmado en equipo:
  - `6c66dbb`
  - Flasheado exitosamente en COM5 con verificación hash y reset OK.

## [V0.0.33] - 2026-02-14
### Notas operativas en CSV + menú Mensajes

- Se agregó nueva columna `notas` al CSV.
- Se agregó opción **Otros** al submenú **Mensajes**.
- Lógica de nota one-shot:
  - Al seleccionar `Camion`, `Humo`, `Construccion` u `Otros`, se guarda esa nota en la próxima fila CSV.
  - Luego se limpia automáticamente para evitar repetición.

## [V0.0.26] - 2026-02-13
### Mejoras en UI y lógica de muestreo

- Se reemplazó el aviso simple por un prompt de confirmación para iniciar/detener muestreo.
- BTN1 cancela la acción y vuelve al menú.
- BTN2 confirma e inicia/detiene el proceso.
- Al confirmar inicio, se fuerza una ejecución inmediata de guardado SD y envío HTTP.
- Se añadieron mensajes por puerto serial para rastrear clics de botones.

## [V0.0.25] - 2026-02-13
### Reestructuración de navegación

- Se eliminó el acceso por pulsación larga.
- Se agregó modo FULL como opción del menú principal.
- La salida de modo FULL se realiza con BTN1 en esa versión.
- Se deshabilitó la función hold para evitar saltos accidentales de pantalla.

## [V0.0.24] - 2026-02-13
### Seguridad de operación

- Se implementó Full Lock para bloquear navegación mientras el dispositivo está en modo de visualización de datos.
- Se sincronizó BTN2 para alternar inicio/parada tanto en menú como en vista bloqueada.

## [V0.0.23] - 2026-02-13
### Versión inicial fusionada

- Integración de backend GPSDebug con UI de menús HIRI_PR0.
- Soporte para sensores PMS5003, SHT31 y SDS198.
- Registro en SD y transmisión HTTP concurrente.

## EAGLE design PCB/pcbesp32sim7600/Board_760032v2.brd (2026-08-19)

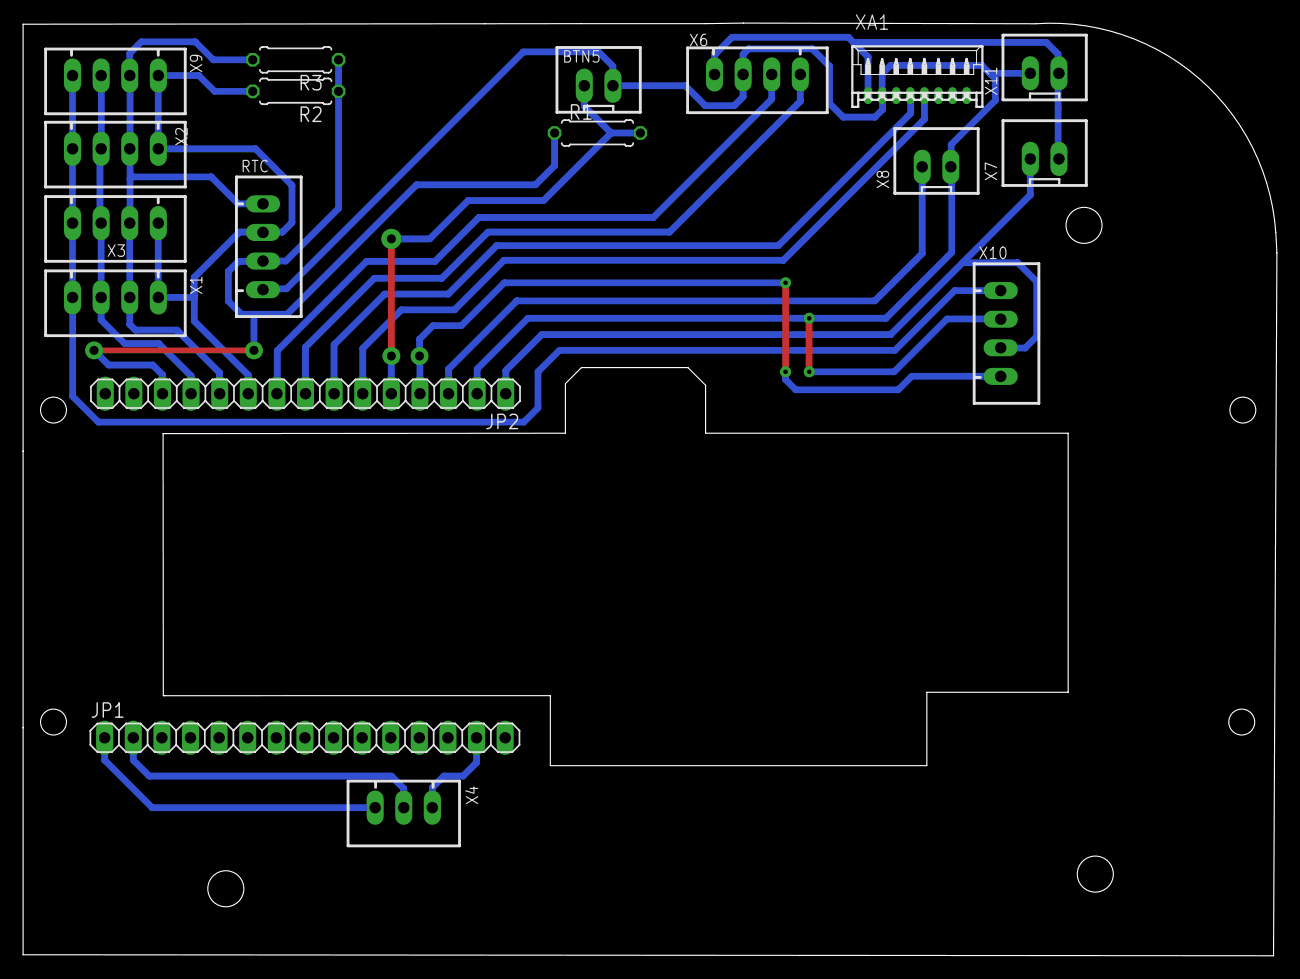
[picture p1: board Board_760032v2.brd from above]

Board: 2 copper layers, 111.3 x 82.8 mm, 18 parts (0 on the bottom side), 16 nets.

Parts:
BTN5: JST-XH-02-PIN-LONG-PAD; JST-XH-02-PACKAGE-LONG-PAD
JP1, JP2: 1X15
R1, R2, R3: 0207/7
RTC: JST-XH-04-PIN-LONG-PAD; JST-XH-04-PACKAGE-LONG-PAD
X1, X2, X3, X6, X9, X10: JST-XH-04-PIN-LONG-PAD; JST-XH-04-PACKAGE-LONG-PAD
X4: JST-XH-03-PIN-LONG-PAD; JST-XH-03-PACKAGE-LONG-PAD
X7: btn0; JST-XH-02-PACKAGE-LONG-PAD
X8, X11: JST-XH-02-PIN-LONG-PAD; JST-XH-02-PACKAGE-LONG-PAD
XA1: 53048-0810; MOLEX_53048-0810

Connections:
0: JP2.4, X10.4
3V3: JP2.13, R1.2, R2.1, R3.1, RTC.3
3V3B: JP1.1, X4.3
BTN: BTN5.1, JP2.5, R1.1
GND: BTN5.2, JP2.2, JP2.12, RTC.4, X1.3, X2.3, X3.3, X6.3, X8.2, X9.3, X10.2, X11.1, XA1.7
GND2: JP1.2, X4.2
OUT: X1.4, X2.4, X3.4, X9.4, X10.1
RGB: JP1.14, X4.1
RST: JP2.3, X8.1
RX1: JP2.9, X6.2
RX2: JP2.7, XA1.5
SCL: JP2.11, R3.2, RTC.1, X1.2, X2.2, X3.2, X9.2
SDA: JP2.10, R2.2, RTC.2, X1.1, X2.1, X3.1, X9.1
TX1: JP2.8, X6.1
TX2: JP2.6, XA1.4
VBUS: JP2.1, X6.4, X7.1, X7.2, X10.3, X11.2, XA1.8

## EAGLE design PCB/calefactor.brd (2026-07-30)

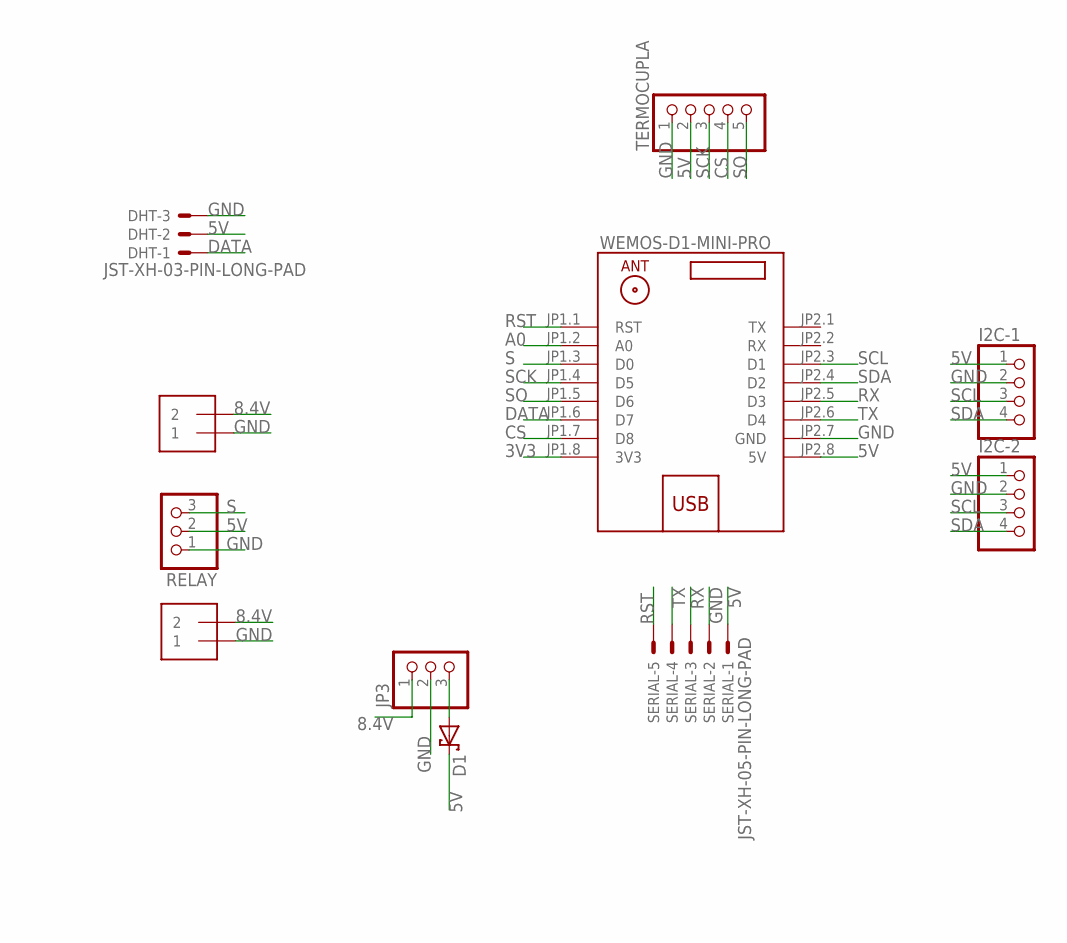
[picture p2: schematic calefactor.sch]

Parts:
D1: SCHOTTKY-DIODEDO41-7; DO41-7
DHT: JST-XH-03-PIN-LONG-PAD; JST-XH-03-PACKAGE-LONG-PAD
I2C-1, I2C-2: PINHD-1X4; 1X04
J1, J2: 1X2-3.5MM
JP3: PINHD-1X3; 1X03
RELAY: PINHD-1X3; 1X03
SERIAL: JST-XH-05-PIN-LONG-PAD; JST-XH-05-PACKAGE-LONG-PAD
TERMOCUPLA: PINHD-1X5; 1X05
U$1: WEMOS-D1-MINI-PRO

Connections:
3V3: U$1.JP1.8 (3V3)
5V: D1.C, DHT.2, I2C-1.1, I2C-2.1, RELAY.2, SERIAL.1, TERMOCUPLA.2, U$1.JP2.8 (5V)
8.4V: J1.2, J2.2, JP3.1
A0: U$1.JP1.2 (A0)
CS: TERMOCUPLA.4, U$1.JP1.7 (D8)
DATA: DHT.1, U$1.JP1.6 (D7)
GND: DHT.3, I2C-1.2, I2C-2.2, J1.1, J2.1, JP3.2, RELAY.1, SERIAL.2, TERMOCUPLA.1, U$1.JP2.7 (GND)
unnamed: D1.A, JP3.3
RST: SERIAL.5, U$1.JP1.1 (RST)
RX: SERIAL.3, U$1.JP2.5 (D3)
S: RELAY.3, U$1.JP1.3 (D0)
SCK: TERMOCUPLA.3, U$1.JP1.4 (D5)
SCL: I2C-1.3, I2C-2.3, U$1.JP2.3 (D1)
SDA: I2C-1.4, I2C-2.4, U$1.JP2.4 (D2)
SO: TERMOCUPLA.5, U$1.JP1.5 (D6)
TX: SERIAL.4, U$1.JP2.6 (D4)

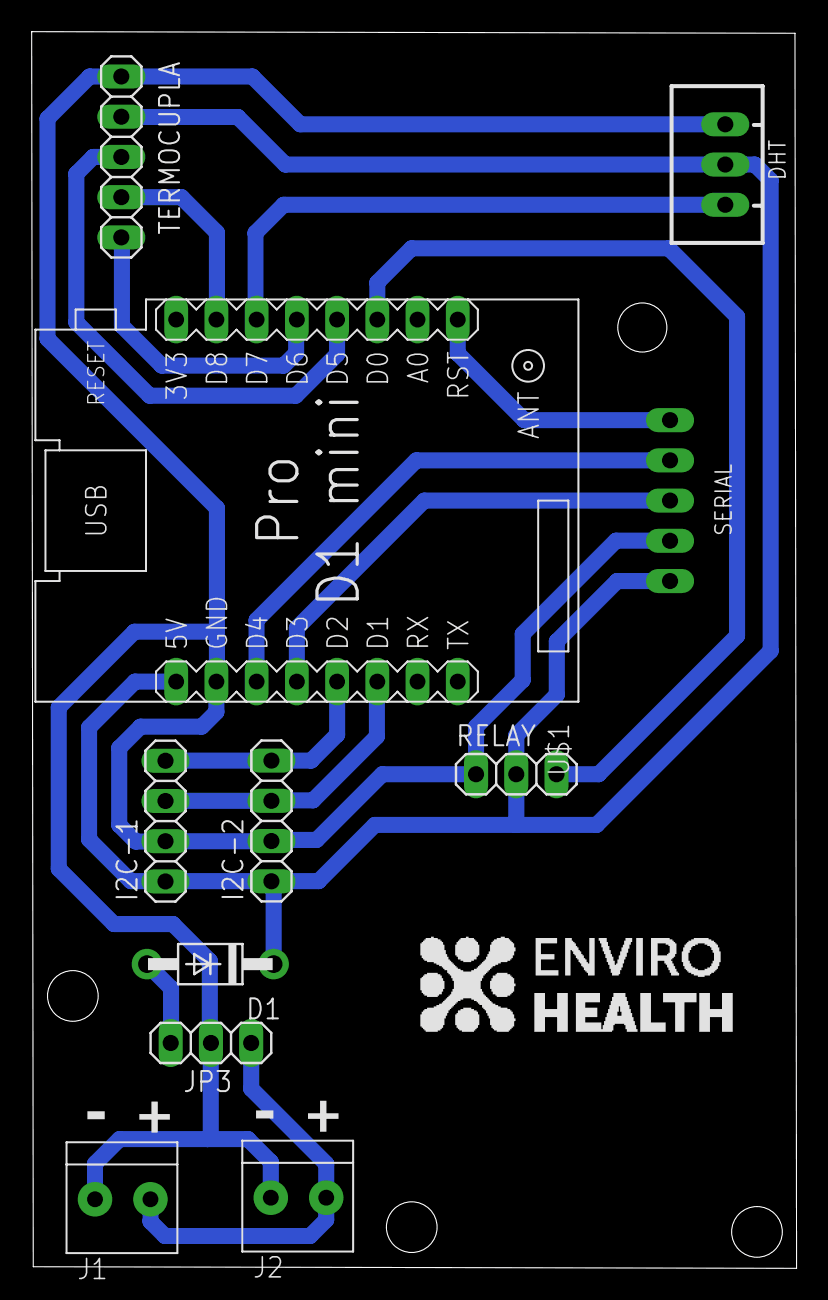
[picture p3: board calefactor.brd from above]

Board: 2 copper layers, 48.3 x 78.1 mm, 11 parts (0 on the bottom side), 14 nets.

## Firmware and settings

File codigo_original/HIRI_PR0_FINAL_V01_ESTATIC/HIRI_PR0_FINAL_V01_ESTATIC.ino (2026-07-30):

/*
 * FirmwarePro.ino - Version Pro V0.1.27R
 * Firmware HIRI PR0 estatico: sensores, GNSS, SD, UI OLED y telemetria HTTP.
 * 
 * Basado en la version Debug 0.1.3V (la mas estable) pero con mejoras de performance:
 * - Modem inicializado de forma sincronica en boot para maxima estabilidad.
 * - Lectura de sensores Serial (SDS198 / PMS) ASINCRONICA (no bloqueante).
 * - I2C con reloj conservador y protecciones contra cuelgues.
 * - Monitoreo de etapas (setStage) y Heartbeat (RAM/Heap).
 */

#include "config.h"
#include "Adafruit_SHT31.h"
#include "Adafruit_SHT4x.h"
#include "DFRobot_MultiGasSensor.h"
#include <DFRobot_ENS160.h>
#include "FS.h"
#include "SD.h"
#include "SPI.h"
#include <Preferences.h>
#include <RTClib.h>
#include <SoftwareSerial.h>
#include <DNSServer.h>
#include <U8g2lib.h>
#include <WebServer.h>
#include <WiFi.h>
#include <Wire.h>
#include <esp_task_wdt.h>

// Modem
#define SerialAT Serial1
TinyGsm modem(SerialAT);

// -------------------- Global Constants --------------------
#define RTC_PROBE_PERIOD_MS 60000
#define RTC_SYNC_THRESHOLD 30
#define MIN_VALID_EPOCH 1672531200 // 2023-01-01
#define WDT_TIMEOUT 60
static const uint32_t I2C_CLOCK_HZ = 50000;
static const uint32_t HEARTBEAT_PERIOD_MS = 10000;
static const uint32_t MODEM_TESTAT_TOTAL_MS = 45000;
static const uint32_t MODEM_TESTAT_RETRY_MS = 1000;

const byte HEADER = 0xAA;
const byte CMD = 0xCF;
const byte TAIL = 0xAB;

String VERSION = "Pro V0.1.27R";

// -------------------- Global States --------------------
bool oledOK;
bool rtcOK = false;
bool SHT31OK = false;
bool SHT4xOK = false;
bool SDS198OK = false;
bool GasOK = false;
bool ENS160OK = false;
bool SDOK = false;
bool wifiModeActive = false;
bool hasRed = false;
bool wdtStarted = false;
const char *lastStage = "BOOT";

SystemConfig config;

// Hardware Objects
U8G2_SSD1306_128X64_NONAME_F_HW_I2C u8g2(U8G2_R0, U8X8_PIN_NONE);
Adafruit_NeoPixel pixels(NUMPIXELS, NEOPIX_PIN, NEO_GRB + NEO_KHZ800);
Adafruit_SHT31 sht31 = Adafruit_SHT31();
Adafruit_SHT4x sht4 = Adafruit_SHT4x();
DFRobot_GAS_I2C gas(&Wire, 0x74);
DFRobot_ENS160_I2C ENS160(&Wire, 0x53);
RTC_DS3231 rtc;
Preferences prefs;
SPIClass spiSD(HSPI);
WebServer server(80);
DNSServer dnsServer;

SoftwareSerial pms(pms_TX, pms_RX);

// Button flags (edge + debounce)
volatile bool btn1ClickFlag = false;
volatile bool btn2ClickFlag = false;
volatile bool btn2HoldFlag = false;
volatile uint32_t lastDebounceTime1 = 0;
volatile uint32_t lastDebounceTime2 = 0;
const uint32_t BTN1_DEBOUNCE_MS = 80;
const uint32_t BTN2_DEBOUNCE_MS = 80;
const uint32_t I2C_POWER_OFF_MS = 250;
const uint32_t I2C_POWER_ON_SETTLE_MS = 700;
const uint32_t BOOT_REVIEW_HOLD_MS = 3000;

// Global Data
uint16_t PM1 = 0, PM25 = 0, PM10 = 0;
float pmsTempC = NAN, pmsHum = NAN;
int SDS198PM100 = 0;
float gasPpm = NAN;
float tempsht31 = NAN, humsht31 = NAN;
float tempsht4x = NAN, humsht4x = NAN;
float rtcTempC = NAN;
float batV = 0.0f;
int csq = 0;
bool networkError = false;
bool streaming = false;
bool loggingEnabled = false;

String gpsLat = "NaN", gpsLon = "NaN";
String gpsTime = "N/A", gpsDate = "N/A";
String satellitesStr = "0", hdopStr = "N/A", gpsAlt = "N/A";
String gpsStatus = "NoFix";
String gpsSpeedKmh = "0.0";

uint8_t debugScreenIndex = 0;
uint32_t lastDebugRotationMs = 0;
const uint32_t DEBUG_ROTATION_INTERVAL_MS = 10000;

String csvFileName = "";
String logFilePath = "";
String failedTxPath = "";
String currentNote = "9";
String lastSavedCSVLine = "";
File uploadFile;
String deviceID = "/HIRIPDUST";
const char *DEVICE_ID_STR = "13"; // Se actualizara desde config o manualmente
String AP_SSID_STR = "";
const char *AP_PASSWORD = "12345678";
String apIpStr = "0.0.0.0";

const char apn[] = "flolive.net";
const char gprsUser[] = "";
const char gprsPass[] = "";
const char *API_BASE = "http://api-sensores.cmasccp.cl/insertarMedicion";
const char *GLOBAL_IDS_VARIABLES = "53,54,55,11,12,15,45,46,4,3,6,7,8,9,51,3,6";

uint32_t sendCounter = 0;
uint32_t sdSaveCounter = 0;
uint32_t lastHttpSend = 0;
uint32_t lastSdSave = 0;
uint32_t lastHttpActivityMs = 0;
uint32_t lastSdActivityMs = 0;
bool lastHttpOk = false;
bool lastSdOk = false;
bool hasHttpAttempted = false;
bool bootHttpAttemptPending = true;
uint8_t lastDayLogged = 0;
bool wasStreamingBeforeBoot = false;

// Animation Variables
int logoXOffset = -25;
int hiriXOffset = 128;
int proYOffset = 64;
const int LOGO_FINAL_X = 4;
const int HIRI_FINAL_X = 48;
const int PRO_FINAL_X = 106;
const int HIRI_FINAL_Y = 44;
const int PRO_FINAL_Y = 52;

// Watchdog, network and diagnostics
String rebootReason = "Unknown";
String networkOperator = "N/A";
String networkTech = "N/A";
String signalQuality = "0";
String registrationStatus = "N/A";
uint32_t lastXtraDownload = 0;
bool xtraSupported = false;
bool xtraLastOk = false;
const uint32_t XTRA_REFRESH_MS = 3UL * 24UL * 60UL * 60UL * 1000UL;
const uint8_t ENS160_INVALID_REINIT_THRESHOLD = 3;
const uint8_t SHT4X_FAIL_REINIT_THRESHOLD = 3;
const uint8_t HTTP_FAIL_MAX_CONSECUTIVE = 6;
const uint32_t HTTP_RETRY_BACKOFF_MS = 60UL * 60UL * 1000UL;
uint8_t httpConsecutiveFailCount = 0;
bool httpBackoffActive = false;
uint32_t httpBackoffUntilMs = 0;
uint8_t ens160InvalidCount = 0;
uint8_t sht4xFailCount = 0;
uint8_t ens160StatusRaw = 0;
uint16_t ens160Tvoc = 0;
uint16_t ens160Eco2 = 0;
uint8_t ens160Aqi = 0;
bool ens160DataValid = false;
char currentCriticalStage[32] = "boot";
RTC_DATA_ATTR char previousResetStage[32] = "boot";
RTC_DATA_ATTR bool previousResetStageValid = false;

// Display State
volatile DisplayState displayState = DISP_NORMAL;
volatile uint32_t displayStateStartTime = 0;
uint32_t lastOledActivity = 0;

const uint8_t BOOT_ITEM_COUNT = 8;
const char *BOOT_ITEM_LABELS[BOOT_ITEM_COUNT] = {
    "I2C", "OLED", "SD", "RTC", "SHT4", "SHT31", "ENS", "GAS"};
char bootItemStatus[BOOT_ITEM_COUNT][6] = {
    "WAIT", "WAIT", "WAIT", "WAIT", "WAIT", "WAIT", "WAIT", "WAIT"};

// Modem Sync
uint8_t rtcModemSyncCount = 0;
uint32_t lastModemSyncAttempt = 0;
const uint32_t MODEM_SYNC_INTERVAL_MS = 600000;
const uint8_t MAX_MODEM_SYNC_COUNT = 3;
bool rtcNetSyncPending = false;
uint32_t rtcNextProbeMs = 0;

// AT Command Struct
struct AtSession {
  bool active = false;
  String expect1;
  String expect2;
  String resp;
  uint32_t deadline = 0;
} at;

// Buffer for PMS
static uint8_t pmsBuf[64];
static size_t pmsHead = 0;
static uint32_t lastPmsSeen = 0;

// Battery Averaging
const float alpha = 0.8;
float batteryVoltageAverage = 0;
static uint32_t lastBatSample = 0;
static float batSampleSum = 0;
static int batSampleCount = 0;
const int NUM_SAMPLES = 30;
const uint32_t BAT_SAMPLE_INTERVAL_MS = 5;

// Variables needed for GPS diag
uint32_t lastNmeaSeenMs = 0;
uint32_t gnssFixFirstMs = 0;
bool gnssFixReported = false;
uint8_t gsaFixType = 0;
uint8_t gsaSatsUsed = 0;
float gsaPdop = NAN, gsaHdop2 = NAN, gsaVdop = NAN;
uint16_t gsvSatsInView = 0;
float gsvSnrAvg = 0, gsvSnrMax = 0;
uint32_t gsvLastMs = 0;
float gsvSnrAcc = 0;
int gsvSnrCnt = 0;
uint32_t lastNmeaMs = 0;
uint32_t lastGgaMs = 0;
uint32_t lastFixMs = 0;
uint16_t nmeaCount1s = 0;
uint16_t nmeaRate = 0;
uint32_t nmeaRefMs = 0;
uint8_t fixQLast = 0;
bool ttffPrinted = false;
uint32_t gnssStartMs = 0;
bool haveFix = false;

// SD Definition constants
const int SD_SCLK = 14, SD_MISO = 2, SD_MOSI = 15, SD_CS = 13;

// -------------------- Prototypes --------------------
void loadConfig();
void saveConfig();
void applyLEDConfig();
void writeErrorLogHeader();
String generateCSVFileName();
void writeCSVHeader();
void drawAnimation();
void startWifiApServer();
void stopWifiApServer();
void renderDisplay();
void oledStatus(const String &l1, const String &l2 = "", const String &l3 = "", const String &l4 = "");
bool saveCSVData();
void checkRebootReason();
void readPMS();
bool readFrameSDS198(byte *buf); // Ahora asincronico
void updatePmLed(float pm25);
void gnssBringUp();
void gnssDiagTick();
void gnssDebugPollAsync();
void gnssWatchdog();
bool atTick(bool &done, bool &ok);
bool atRun(const String &cmd, const String &expect1 = "OK", const String &expect2 = "ERROR", uint32_t timeout_ms = 8000);
bool sendAtSync(const String &cmd, String &resp, uint32_t timeout_ms = 4000);
bool httpGet_webhook(const String &url);
bool detectAndEnableXtra();
bool downloadXtraOnce();
void parseNMEA(const String &line);
void saveFailedTransmission(const String &url, const String &errorType);
bool sendCurrentMeasurement();
void handleButtonLogic();
void showMessage(const char *msg);
void processSerialCommand();
void logError(const String &type, const String &ctx, const String &msg);
void IRAM_ATTR isr_btn2();
void initI2CSensors();
void recoverI2CBus(const char *reason);
void updateEns160State();
bool i2cDevicePresent(uint8_t address);
void setI2CPower(bool enabled);
void powerCycleI2CDevices(const char *reason);
void bootStatus(const String &stage, const String &detail, bool ok);
void renderBootWindow();
extern void ui_btn1_click();
extern void ui_btn2_click();
extern bool uiFullMode;
String missingUrlValue();
String safeFloatStr(float v);
String safeUIntStr(uint32_t v);
String safeIntStr(int v);
String safeNumberStr(const String &s);
String safeGpsStr(const String &s);
String safeSatsStr(const String &s);

// -------------------- Debug Helpers --------------------
void feedWdt() { if (wdtStarted) esp_task_wdt_reset(); }
void startWdtOnce() {
  if (!wdtStarted) {
    esp_task_wdt_init(WDT_TIMEOUT, true);
    esp_task_wdt_add(NULL);
    wdtStarted = true;
    Serial.println("[WDT] Started");
  }
}
void setStage(const char *stage) {
  if (stage == nullptr) {
    return;
  }
  strncpy(currentCriticalStage, stage, sizeof(currentCriticalStage) - 1);
  currentCriticalStage[sizeof(currentCriticalStage) - 1] = '\0';
  strncpy(previousResetStage, currentCriticalStage, sizeof(previousResetStage) - 1);
  previousResetStage[sizeof(previousResetStage) - 1] = '\0';
  previousResetStageValid = true;
  lastStage = currentCriticalStage;
}

void printHeartbeat() {
  static uint32_t lastHeartbeatMs = 0;
  if (millis() - lastHeartbeatMs < HEARTBEAT_PERIOD_MS) return;
  lastHeartbeatMs = millis();
  Serial.printf("[HB] ms=%lu stage=%s heap=%u sd=%d stream=%d batV=%.3f\n", 
                millis(), lastStage, ESP.getFreeHeap(), SDOK, streaming, batV);
}

void configureI2CBus() {
  setStage("i2c.begin");
  Wire.begin();
  Wire.setTimeOut(50);
  Wire.setClock(I2C_CLOCK_HZ);
  delay(50);
  Serial.printf("[I2C] Clock: %u Hz\n", I2C_CLOCK_HZ);
}

bool i2cDevicePresent(uint8_t address) {
  Wire.beginTransmission(address);
  return Wire.endTransmission() == 0;
}

void setI2CPower(bool enabled) {
#if I2C_POWER_PIN >= 0
  digitalWrite(I2C_POWER_PIN, enabled ? HIGH : LOW);
  Serial.printf("[I2C_PWR] GPIO%d=%s\n", I2C_POWER_PIN,
                enabled ? "HIGH" : "LOW");
#endif
}

void powerCycleI2CDevices(const char *reason) {
  Serial.printf("[I2C_PWR] Power cycle: %s\n", reason ? reason : "manual");
  setI2CPower(false);
  delay(I2C_POWER_OFF_MS);
  setI2CPower(true);
  delay(I2C_POWER_ON_SETTLE_MS);
}

void initI2CSensors() {
  setStage("i2c.sensors.init");

  bootStatus("SHT4X", "probando...", true);
  if (!sht4.begin()) {
    SHT4xOK = false;
    logError("I2C_SENSOR_FAIL", "SHT4X.begin", "SHT4x not found");
    bootStatus("SHT4X", "no detectado", false);
  } else {
    sht4.setPrecision(SHT4X_HIGH_PRECISION);
    sht4.setHeater(SHT4X_NO_HEATER);
    SHT4xOK = true;
    sht4xFailCount = 0;
    Serial.println("[SHT4X] OK");
    bootStatus("SHT4X", "OK", true);
  }
  feedWdt();
  yield();

  bootStatus("SHT31", "probando...", true);
  if (!sht31.begin(0x44)) {
    SHT31OK = false;
    logError("I2C_SENSOR_FAIL", "SHT31.begin", "SHT31 not found");
    bootStatus("SHT31", "no detectado", false);
  } else {
    SHT31OK = true;
    Serial.println("[SHT31] OK");
    bootStatus("SHT31", "OK", true);
  }
  feedWdt();
  yield();

  bootStatus("ENS160", "probando...", true);
  if (NO_ERR != ENS160.begin()) {
    ENS160OK = false;
    ens160DataValid = false;
    logError("I2C_SENSOR_FAIL", "ENS160.begin", "ENS160 init failed");
    bootStatus("ENS160", "no detectado", false);
  } else {
    ENS160.setPWRMode(ENS160_STANDARD_MODE);
    ENS160OK = true;
    ens160InvalidCount = 0;
    ens160DataValid = false;
    Serial.println("[ENS160] OK");
    bootStatus("ENS160", "OK", true);
  }
  feedWdt();
  yield();
}

void recoverI2CBus(const char *reason) {
  logError("I2C_RECOVER", "recoverI2CBus", reason);
  setStage("i2c.recover");
  Wire.end();
  delay(50);
  powerCycleI2CDevices(reason);
  configureI2CBus();
  oledOK = i2cDevicePresent(0x3C) || i2cDevicePresent(0x3D);
  if (oledOK) {
    u8g2.begin();
    u8g2.setDisplayRotation(config.rotateDisplay ? U8G2_R0 : U8G2_R2);
  }
  initI2CSensors();
  bootStatus("GAS", "probando...", true);
  if (!gas.begin()) {
    GasOK = false;
    bootStatus("GAS", "no detectado", false);
  } else {
    gas.changeAcquireMode(gas.PASSIVITY);
    gas.setTempCompensation(gas.ON);
    GasOK = true;
    bootStatus("GAS", "OK", true);
  }
}

void updateEns160State() {
  if (!ENS160OK) {
    ens160DataValid = false;
    return;
  }

  setStage("ens160.read");
  float tc = !isnan(tempsht4x) ? tempsht4x : (!isnan(tempsht31) ? tempsht31 : pmsTempC);
  float hc = !isnan(humsht4x) ? humsht4x : (!isnan(humsht31) ? humsht31 : pmsHum);
  if (!isnan(tc) && !isnan(hc)) {
    ENS160.setTempAndHum(tc, hc);
  }

  ens160StatusRaw = ENS160.getENS160Status();
  ens160Aqi = ENS160.getAQI();
  ens160Tvoc = ENS160.getTVOC();
  ens160Eco2 = ENS160.getECO2();

  bool statusOk = (ens160StatusRaw <= 0x02);
  bool valuesOk = (ens160Aqi >= 1U && ens160Aqi <= 5U &&
                   ens160Tvoc <= 65000U &&
                   ens160Eco2 >= 400U && ens160Eco2 <= 65000U);
  ens160DataValid = statusOk && valuesOk;

  Serial.printf("[ENS160] status=%u aqi=%u tvoc=%u eco2=%u valid=%d\n",
                ens160StatusRaw, ens160Aqi, ens160Tvoc, ens160Eco2,
                ens160DataValid);

  if (ens160DataValid || ens160StatusRaw == 0x01 || ens160StatusRaw == 0x02) {
    if (ens160DataValid) ens160InvalidCount = 0;
    return;
  }

  if (++ens160InvalidCount >= ENS160_INVALID_REINIT_THRESHOLD) {
    ens160InvalidCount = 0;
    recoverI2CBus("ENS160 invalid threshold");
  }
}

void enforceStationStartupConfig() {
  bool changed = false;

  if (!config.sdAutoMount) { config.sdAutoMount = true; changed = true; }
  if (config.sdSavePeriod != 180000UL) { config.sdSavePeriod = 180000UL; changed = true; }
  if (config.httpSendPeriod != 300000UL) { config.httpSendPeriod = 300000UL; changed = true; }
  if (!config.autostart) { config.autostart = true; changed = true; }
  if (config.autostartWaitGps) { config.autostartWaitGps = false; changed = true; }
  if (!config.autoDebug) { config.autoDebug = true; changed = true; }

  if (changed) {
    saveConfig();
    Serial.println("[CONFIG] Station startup enforced: autostart/debug ON, HTTP 5min, SD 3min");
  }
}

// -------------------- OLED Helper --------------------
void oledStatus(const String &l1, const String &l2, const String &l3, const String &l4) {
  if (!oledOK) return;
  u8g2.clearBuffer();
  u8g2.setFont(u8g2_font_5x7_tf);
  u8g2.setCursor(0, 12); u8g2.print(l1);
  u8g2.setCursor(0, 26); u8g2.print(l2);
  u8g2.setCursor(0, 40); u8g2.print(l3);
  u8g2.setCursor(0, 54); u8g2.print(l4);
  u8g2.sendBuffer();
}

int bootIndexForStage(const String &stage) {
  if (stage == "I2C" || stage == "I2C PWR") return 0;
  if (stage == "OLED") return 1;
  if (stage == "SD") return 2;
  if (stage == "RTC") return 3;
  if (stage == "SHT4X" || stage == "SHT4") return 4;
  if (stage == "SHT31") return 5;
  if (stage == "ENS160" || stage == "ENS") return 6;
  if (stage == "GAS") return 7;
  return -1;
}

void renderBootWindow() {
  if (!oledOK) return;
  u8g2.clearBuffer();
  u8g2.setFont(u8g2_font_5x7_tf);
  u8g2.drawStr(0, 7, "REVISION INICIO");
  u8g2.drawHLine(0, 9, 128);
  u8g2.setFont(u8g2_font_4x6_tf);
  for (uint8_t i = 0; i < BOOT_ITEM_COUNT; ++i) {
    int y = 16 + (i * 6);
    u8g2.setCursor(0, y);
    u8g2.print(BOOT_ITEM_LABELS[i]);
    u8g2.setCursor(96, y);
    u8g2.print(bootItemStatus[i]);
  }
  u8g2.sendBuffer();
}

void bootStatus(const String &stage, const String &detail, bool ok) {
  const char *state = detail.startsWith("probando") ? "..." : (ok ? "OK" : "FAIL");
  Serial.printf("[BOOTCHK] %-12s %-4s %s\n", stage.c_str(), state, detail.c_str());

  int idx = bootIndexForStage(stage);
  if (idx >= 0) {
    strncpy(bootItemStatus[idx], state, sizeof(bootItemStatus[idx]) - 1);
    bootItemStatus[idx][sizeof(bootItemStatus[idx]) - 1] = '\0';
    renderBootWindow();
  }
}

// -------------------- AT Helpers --------------------
void atBegin(const String &cmd, const String &expect1, const String &expect2, uint32_t timeout_ms) {
  modem.stream.print("AT");
  modem.stream.println(cmd);
  at.active = true;
  at.expect1 = expect1;
  at.expect2 = expect2;
  at.resp = "";
  at.deadline = millis() + timeout_ms;
}

bool atTick(bool &done, bool &ok) {
  uint32_t t0 = millis();
  while (SerialAT.available()) {
    if ((millis() - t0) >= 20) { done = false; ok = false; return false; }
    String line = SerialAT.readStringUntil('\n');
    line.trim();
    if (line.isEmpty()) continue;
    if (line.charAt(0) == '$') { parseNMEA(line); continue; }
    if (!at.active) continue;
    if (at.resp.length() < 2048) { at.resp += line; at.resp += "\n"; }
    if (at.expect1.length() && line.indexOf(at.expect1) >= 0) { done = true; ok = true; at.active = false; return true; }
    if (at.expect2.length() && line.indexOf(at.expect2) >= 0) { done = true; ok = (at.expect2 == "OK"); at.active = false; return true; }
  }
  if (at.active && millis() > at.deadline) { done = true; ok = false; at.active = false; return true; }
  done = false; ok = false; return false;
}

bool atRun(const String &cmd, const String &expect1, const String &expect2, uint32_t timeout_ms) {
  atBegin(cmd, expect1, expect2, timeout_ms);
  bool done = false, ok = false;
  uint32_t hardDeadline = millis() + timeout_ms + 1000;
  while (!done && millis() < hardDeadline) { feedWdt(); if (atTick(done, ok)) break; delay(1); }
  at.active = false;
  return ok;
}

bool sendAtSync(const String &cmd, String &resp, uint32_t timeout_ms) {
  atBegin(cmd, "OK", "ERROR", timeout_ms);
  bool done = false, ok = false;
  uint32_t hardDeadline = millis() + timeout_ms + 1000;
  while (!done && millis() < hardDeadline) { feedWdt(); if (atTick(done, ok)) break; delay(1); }
  resp = at.resp;
  at.active = false;
  return ok;
}

void updateNetworkInfo() {
  String resp;
  if (sendAtSync("+COPS?", resp, 3000)) {
    int idx = resp.indexOf("+COPS:");
    if (idx >= 0) {
      int start = resp.indexOf('"', idx);
      int end = resp.indexOf('"', start + 1);
      if (start >= 0 && end > start) networkOperator = resp.substring(start + 1, end);
    }
  }
  if (sendAtSync("+CREG?", resp, 2000)) {
    if (resp.indexOf(",1") >= 0 || resp.indexOf(",5") >= 0) registrationStatus = "Registered";
    else registrationStatus = "NotRegistered";
  }
}
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
void loop() {
  feedWdt(); setStage("loop.start"); printHeartbeat();
  handleButtonLogic();

  if (wifiModeActive) {
    dnsServer.processNextRequest(); server.handleClient();
    if (haveFix) gnssWatchdog();
    return;
  }

  gnssWatchdog(); gnssDiagTick(); gnssDebugPollAsync();

  static uint32_t lastSensorUpdateMs = 0;
  if (millis() - lastSensorUpdateMs >= 2000) {
    lastSensorUpdateMs = millis();
    refreshSensors2s();
  }

  if (FirstLoop) {
    csq = modem.getSignalQuality(); updateNetworkInfo();
    FirstLoop = false;
  }

  readPMS();
  static uint32_t lastLedUpdateMs = 0;
  if (millis() - lastLedUpdateMs >= 300) { lastLedUpdateMs = millis(); updatePmLed((float)PM25); }

  byte frame[10];
  if (readFrameSDS198(frame)) {
    SDS198PM100 = (uint16_t)((frame[5] << 8) | frame[4]);
    SDS198OK = true;
  }

  static uint32_t lastAtTick = 0;
  if (millis() - lastAtTick >= 50) {
    lastAtTick = millis(); bool d, o; (void)atTick(d, o);
  }

  if (millis() - lastBatSample >= BAT_SAMPLE_INTERVAL_MS) {
    lastBatSample = millis(); batSampleSum += analogRead(BAT_PIN); batSampleCount++;
    if (batSampleCount >= NUM_SAMPLES) {
      batV = (batSampleSum / NUM_SAMPLES / 4095.0f) * 3.3f * 2.0f * 1.15f;
      batSampleSum = 0; batSampleCount = 0;
    }
  }

  static uint32_t lastDisplayUpdate = 0;
  if (millis() - lastDisplayUpdate > 60) { lastDisplayUpdate = millis(); renderDisplay(); }

  if (loggingEnabled && (millis() - lastSdSave >= config.sdSavePeriod)) {
    lastSdSave = millis(); Serial.println("[SD] Save");
    lastSdOk = saveCSVData(); lastSdActivityMs = millis();
  }

  if (streaming && (millis() - lastHttpSend >= config.httpSendPeriod)) {
    lastHttpSend = millis(); Serial.println("[HTTP] Send");
    lastHttpOk = sendCurrentMeasurement();
    hasHttpAttempted = true;
    lastHttpActivityMs = millis();
  }

  processSerialCommand();
}

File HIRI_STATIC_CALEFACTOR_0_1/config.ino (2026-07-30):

// -------------------- Configuration System --------------------
// Sistema de configuración persistente en flash (Preferences)
// Configuración accesible por comandos seriales
// NOTA: struct SystemConfig y variable config están declaradas en el archivo
// ESTA confirguracion es la final para HIRIVALPO
// principal

// -------------------- Load Configuration --------------------
void loadConfig() {
  prefs.begin("config", false);

  // SD
  config.sdAutoMount = prefs.getBool("sdAuto", true);//vamos a cargar la sd automaticamente true
  config.sdSavePeriod = prefs.getUInt("sdSavePer", 180000); // 3 minutos

  // HTTP
  config.httpSendPeriod = prefs.getUInt("httpPer", 300000); // 5 minutos
  config.httpTimeout = prefs.getUShort("httpTO", 15);

  // Display
  config.oledAutoOff = prefs.getBool("oledOff", false);
  config.oledTimeout = prefs.getUInt("oledTO", 120000);

  // Power
  config.ledEnabled = prefs.getBool("ledEn", true);
  config.ledBrightness = prefs.getUChar("ledBr", 50);

  // Autostart
  config.autostart = prefs.getBool("autoStart", true);
  config.autostartWaitGps = prefs.getBool("autoGPS", false);
  config.autostartGpsTimeout = prefs.getUShort("autoGPSTO", 600);
  // System
  config.rotateDisplay = prefs.getBool("rotDisp", true); //false originalmente rotado para estas estaciones
  config.scheduledRebootHours = prefs.getUShort("rebootH", 3);
  config.gnssEnabled = prefs.getBool("gnssEn", false);

  // GNSS Mode
  config.gnssMode = prefs.getUChar("gnssMode", 15);

  prefs.end();

  Serial.println("[CONFIG] Loaded from flash");
  Serial.printf("[CONFIG] SD auto-mount: %s, save period: %lums\n",
                config.sdAutoMount ? "ON" : "OFF", config.sdSavePeriod);
  Serial.printf("[CONFIG] HTTP send period: %lums, timeout: %us\n",
                config.httpSendPeriod, config.httpTimeout);
  Serial.printf("[CONFIG] OLED auto-off: %s, timeout: %lums\n",
                config.oledAutoOff ? "ON" : "OFF", config.oledTimeout);
  Serial.printf("[CONFIG] LED enabled: %s, brightness: %u%%\n",
                config.ledEnabled ? "YES" : "NO", config.ledBrightness);
  Serial.printf("[CONFIG] Autostart: %s, wait GPS: %s, GPS timeout: %us\n",
                config.autostart ? "YES" : "NO",
                config.autostartWaitGps ? "YES" : "NO",
                config.autostartGpsTimeout);
  Serial.printf("[CONFIG] Rotate Display: %s\n", config.rotateDisplay ? "YES" : "NO");
  if (config.scheduledRebootHours == 0) {
    Serial.println("[CONFIG] Scheduled reboot: disabled");
  } else {
    Serial.printf("[CONFIG] Scheduled reboot: every %u hours\n",
                  config.scheduledRebootHours);
  }
  Serial.printf("[CONFIG] GNSS enabled: %s\n", config.gnssEnabled ? "YES" : "NO");
  Serial.printf("[CONFIG] GNSS mode: %u\n", config.gnssMode);

}

// -------------------- Save Configuration --------------------
void saveConfig() {
  prefs.begin("config", false);

  // SD
  prefs.putBool("sdAuto", config.sdAutoMount);
  prefs.putUInt("sdSavePer", config.sdSavePeriod);

  // HTTP
  prefs.putUInt("httpPer", config.httpSendPeriod);
  prefs.putUShort("httpTO", config.httpTimeout);

  // Display
  prefs.putBool("oledOff", config.oledAutoOff);
  prefs.putUInt("oledTO", config.oledTimeout);

  // Power
  prefs.putBool("ledEn", config.ledEnabled);
  prefs.putUChar("ledBr", config.ledBrightness);

  // Autostart
  prefs.putBool("autoStart", config.autostart);
  prefs.putBool("autoGPS", config.autostartWaitGps);
  prefs.putUShort("autoGPSTO", config.autostartGpsTimeout);
  // System
  prefs.putBool("rotDisp", config.rotateDisplay);
  prefs.putUShort("rebootH", config.scheduledRebootHours);
  prefs.putBool("gnssEn", config.gnssEnabled);

  // GNSS Mode
  prefs.putUChar("gnssMode", config.gnssMode);

  prefs.end();

  Serial.println("[CONFIG] Saved to flash");
}

// -------------------- Reset to Defaults -------------------- 
//cambiado a modo estacion
void configSetDefaults() {
  config.sdAutoMount = true; // NO montar en boot por defecto false
  config.sdSavePeriod = 180000; // 3 minutos

  config.httpSendPeriod = 300000; // 5 minutos 
  config.httpTimeout = 15;      // 15 segundos

  config.oledAutoOff = false;  // Siempre encendida
  config.oledTimeout = 120000; // 2 minutos

  config.ledEnabled = true;  // LED habilitado
  config.ledBrightness = 50; // 50% brillo

  config.autostart = true;         // SI autostart
  config.autostartWaitGps = false;  // NO esperar GPS
  config.autostartGpsTimeout = 600; // 10 minutos (default)
  config.rotateDisplay = false;     // Display NO rotado
  config.scheduledRebootHours = 3;   // Reinicio programado cada 3 horas; 0 deshabilita
  config.gnssEnabled = false;       // GNSS apagado por defecto

  config.gnssMode = 15; // Todas las constelaciones (default)

  Serial.println("[CONFIG] Reset to defaults");
}
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

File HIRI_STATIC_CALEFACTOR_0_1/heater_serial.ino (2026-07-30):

// Enlace serial HIRI <-> calefactor. Tramas ASCII, 9600 8N1:
// CALEF,1,HELLO,version*HH (tambien acepta el ID historico CAL)
// CALEF,1,VERSION,version*HH
// CALEF,1,DATA,extTemp,shtTemp,bmeTemp,shtHum,bmeHum,thermo,relay,byHum,byTemp,emergency*HH
// HIRI,1,HELLO*HH, HIRI,1,VERSION*HH, HIRI,1,TEMP,valor*HH y
// HIRI,1,CAL,segundos*HH

static String heaterRxLine;
static uint32_t heaterLastHelloMs = 0;
static uint32_t heaterLastTempTxMs = 0;
static uint32_t heaterLastVersionRequestMs = 0;
static uint32_t heaterVersionQueryStartedMs = 0;
static bool heaterVersionQueryActive = false;
static const uint32_t HEATER_HELLO_INTERVAL_MS = 5000;
static const uint32_t HEATER_TEMP_INTERVAL_MS = 2000;
static const uint32_t HEATER_VERSION_RETRY_MS = 30000;
static const uint32_t HEATER_VERSION_QUERY_WINDOW_MS = 3UL * 60UL * 1000UL;
static const uint32_t HEATER_STALE_MS = 5000;
static const uint16_t HEATER_MAX_TEST_SECONDS = 300;

bool heaterDeviceIdIsValid(const String &deviceId) {
  return deviceId == "CALEF" || deviceId == "CAL";
}

uint8_t heaterChecksum(const String &payload) {
  uint8_t sum = 0;
  for (size_t i = 0; i < payload.length(); ++i) sum += (uint8_t)payload[i];
  return sum;
}

bool heaterFrameIsValid(const String &frame, String &payload) {
  int star = frame.lastIndexOf('*');
  if (star <= 0 || star + 3 != frame.length()) return false;
  payload = frame.substring(0, star);
  char expected[3];
  snprintf(expected, sizeof(expected), "%02X", heaterChecksum(payload));
  String received = frame.substring(star + 1);
  received.toUpperCase();
  return received == expected;
}

void heaterSendFrame(const String &payload) {
  char checksum[4];
  snprintf(checksum, sizeof(checksum), "*%02X", heaterChecksum(payload));
  Serial2.print(payload);
  Serial2.println(checksum);
  Serial.println("[CALEFACTOR][TX] " + payload + checksum);
}

bool heaterRequestTimedTest(const String &secondsText) {
  if (secondsText.length() == 0) return false;

  for (size_t i = 0; i < secondsText.length(); ++i) {
    if (!isDigit(secondsText[i])) return false;
  }

  unsigned long seconds = secondsText.toInt();
  if (seconds == 0 || seconds > HEATER_MAX_TEST_SECONDS) return false;

  heaterSendFrame("HIRI,1,CAL," + String(seconds));
  Serial.printf("[CALEFACTOR] prueba solicitada: %lu s\n", seconds);
  return true;
}

bool heaterParseData(const String &payload) {
  // Se esperan el ID, version de protocolo, DATA y 10 valores posteriores.
  const uint8_t expectedFields = 13;
  String fields[13];
  int begin = 0;
  for (uint8_t i = 0; i < expectedFields; ++i) {
    int comma = payload.indexOf(',', begin);
    if (comma < 0) {
      fields[i] = payload.substring(begin);
      begin = payload.length();
    } else {
      fields[i] = payload.substring(begin, comma);
      begin = comma + 1;
    }
  }
  if (!heaterDeviceIdIsValid(fields[0]) || fields[1] != "1" ||
      fields[2] != "DATA") {
    return false;
  }

  heaterExternalTemp = fields[3].toFloat();
  heaterShtTemp = fields[4].toFloat();
  heaterBmeTemp = fields[5].toFloat();
  heaterShtHum = fields[6].toFloat();
  heaterBmeHum = fields[7].toFloat();
  heaterThermoTemp = fields[8].toFloat();
  heaterRelayOn = fields[9].toInt() != 0;
  heaterByHumidity = fields[10].toInt() != 0;
  heaterByTemperature = fields[11].toInt() != 0;
  heaterEmergencyMode = fields[12].toInt() != 0;
  heaterLastDataMs = millis();
  heaterConnected = true;
  Serial.printf("[CALEFACTOR][RX] SHT=%.1fC/%.1f%% BME=%.1fC/%.1f%% TERM=%.1fC REL=%d H=%d T=%d E=%d\n",
                heaterShtTemp, heaterShtHum, heaterBmeTemp, heaterBmeHum,
                heaterThermoTemp, heaterRelayOn, heaterByHumidity,
                heaterByTemperature, heaterEmergencyMode);
  return true;
}

void heaterProcessFrame(String frame) {
  frame.trim();
  if (frame.length() == 0) return;
  Serial.println("[CALEFACTOR][RX RAW] " + frame);
  String payload;
  if (!heaterFrameIsValid(frame, payload)) {
    Serial.println("[CALEFACTOR] trama/checksum invalido");
    return;
  }
  int firstComma = payload.indexOf(',');
  String deviceId = firstComma > 0 ? payload.substring(0, firstComma) : "";
  String message = firstComma > 0 ? payload.substring(firstComma + 1) : "";

  bool isHello = message == "1,HELLO" || message.startsWith("1,HELLO,");
  if (heaterDeviceIdIsValid(deviceId) && isHello) {
    heaterConnected = true;
    String helloVersion = message.startsWith("1,HELLO,")
                              ? message.substring(String("1,HELLO,").length())
                              : "";
    if (helloVersion.length() > 0) {
      heaterFirmwareVersion = helloVersion;
      heaterVersionKnown = true;
      heaterVersionQueryActive = false;
    }
    Serial.println("[CALEFACTOR] conectado: " + payload);
  } else if (heaterDeviceIdIsValid(deviceId) &&
             message.startsWith("1,VERSION,")) {
    String receivedVersion =
        message.substring(String("1,VERSION,").length());
    if (receivedVersion.length() == 0) {
      Serial.println("[CALEFACTOR] respuesta VERSION vacia");
      return;
    }
    heaterFirmwareVersion = receivedVersion;
    heaterVersionKnown = true;
    heaterVersionQueryActive = false;
    heaterConnected = true;
    Serial.println("[CALEFACTOR] firmware: " + heaterFirmwareVersion);
  } else if (heaterParseData(payload)) {
    // Los valores ya fueron impresos por heaterParseData().
  } else {
    Serial.println("[CALEFACTOR] trama valida, pero ID/tipo no reconocido");
  }
}

void heaterReadAvailableFrames() {
  while (Serial2.available() > 0) {
    char c = (char)Serial2.read();
    if (c == '\n') {
      heaterProcessFrame(heaterRxLine);
      heaterRxLine = "";
    } else if (c != '\r') {
      if (heaterRxLine.length() < 180) heaterRxLine += c;
      else heaterRxLine = ""; // descarta una trama demasiado larga
    }
  }
}

void heaterRequestFirmwareVersion() {
  uint32_t now = millis();
  if (!heaterVersionQueryActive) {
    heaterVersionQueryActive = true;
    heaterVersionQueryStartedMs = now;
  }
  heaterSendFrame("HIRI,1,VERSION");
  heaterLastVersionRequestMs = now;
}
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

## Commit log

2026-08-19 Refactor code structure for improved readability and maintainability
    [Board_760032v2.brd, Board_760032v2.sch]
2026-08-19 Update README to include PCB design details for HIRI ESP32/SIM7600 station
2026-09-14 Update firmware version to V1.0.2 and enhance connection handling with improved error management and SD mode documentation
    [HIRI_STATIC_CALEFACTOR_0_1.ino, config.h, gps.ino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]

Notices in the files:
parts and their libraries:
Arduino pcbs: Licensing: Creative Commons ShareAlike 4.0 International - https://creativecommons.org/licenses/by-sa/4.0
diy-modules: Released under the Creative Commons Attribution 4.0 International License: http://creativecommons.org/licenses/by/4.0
